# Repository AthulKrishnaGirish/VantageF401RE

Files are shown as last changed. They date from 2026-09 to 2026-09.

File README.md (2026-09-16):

# VantageF401RE

### STM32F401RE Evaluation & Development Board

**Mixed Traces PCB Design Competition — 2026  —**
**Submission by, Athul Krishna Girish**

---

## Project Overview

**VantageF401RE** is an independently designed, compact **2-layer STM32F401RE-based evaluation and development board** developed in KiCad as part of the **Mixed Traces PCB Design Competition 2026**.

The board is built around the **STM32F401RET6** microcontroller and integrates the essential features expected from a development board, including regulated power, USB connectivity, SWD programming/debugging, UART, SPI, I²C, GPIO expansion, reset and boot control, user indicators, and supporting protection and decoupling circuitry.

The design was developed independently with the **STM32 NUCLEO-F401RE** used as a functional and architectural reference. The VantageF401RE schematic, component arrangement, PCB placement, and routing were independently developed and are not a direct copy of the NUCLEO PCB layout.

---

## Project Status

### Completed — Final Design

The VantageF401RE schematic and PCB layout have been completed in KiCad.

The project includes:

- Complete STM32F401RET6-based schematic
- Power supply and 3.3 V regulation
- USB-C power and USB 2.0 interface
- USB ESD protection
- SWD programming/debugging interface
- UART interface
- SPI interface
- I²C interface
- GPIO expansion
- Reset and BOOT selection circuitry
- User button and LED
- Power and USB status indicators
- External 5 V input
- Crystal oscillator
- MCU power decoupling
- Test points
- Two-layer PCB layout
- Ground copper zones
- ERC and DRC verification
- Final Gerber and drill file generation
- Final component list and design documentation

The final PCB design achieved **0 reported DRC errors**, and the final manufacturing files were generated from the completed PCB layout.

> **Note:** The project was developed and verified as a PCB design in KiCad. No physical fabrication or hardware testing is claimed as part of this submission.

---

## Key Specifications

| Parameter | Specification |
|---|---|
| **Board Name** | VantageF401RE |
| **MCU** | STM32F401RET6 |
| **MCU Package** | LQFP-64 |
| **PCB Layers** | 2 copper layers |
| **PCB Dimensions** | 80 mm × 60 mm |
| **Design Software** | KiCad |
| **Logic Supply** | 3.3 V |
| **USB Interface** | USB Type-C / USB 2.0 |
| **Programming & Debugging** | SWD |
| **Communication Interfaces** | UART, SPI, I²C |
| **GPIO Expansion** | 20-pin header |
| **External Power** | 5 V input |
| **PCB Verification** | ERC / DRC |
| **Fabrication Requirement** | Not required |

---

## Main Features

### 1. STM32F401RET6 Core

The board uses the **STM32F401RET6**, a 64-pin LQFP STM32F4-series microcontroller.

The MCU section includes:

- 3.3 V digital supply
- Analog supply connection
- VCAP capacitor
- Local decoupling capacitors
- External HSE crystal
- Reset circuitry
- BOOT0 configuration
- SWD programming/debugging access

---

### 2. Power Supply

The board provides a regulated **3.3 V supply** for the STM32F401RET6 and peripheral circuitry.

**Power inputs**

- USB-C 5 V input
- External 5 V input

**Regulation**

An **AP2112K-3.3 LDO regulator** converts the incoming 5 V supply to 3.3 V.

The power section includes:

- Input decoupling
- Output decoupling
- 3.3 V bulk capacitance
- Power indication
- External-input protection

An **SS14 Schottky diode** is included on the external 5 V input path for protection.

---

### 3. USB-C Interface

The board provides a USB Type-C connector for power and USB 2.0 data connectivity.

The USB section includes:

- USB-C receptacle
- USB 2.0 D+ and D− connections
- CC1 and CC2 configuration resistors
- USB ESD protection
- USB D+ and D− series resistors
- USB status indicator

The USB data path uses the STM32F401RE USB pins:

- **PA11 — USB_DM**
- **PA12 — USB_DP**

---

### 4. USB ESD Protection

A **USBLC6-2SC6** protection device is placed close to the USB connector.

The protection network is incorporated into the USB data path to provide ESD protection for the USB D+ and D− lines.

The USB signal path is organized as:

```text
USB-C
  ↓
USB D+ / D−
  ↓
USB ESD Protection
  ↓
22 Ω Series Resistors
  ↓
STM32F401RET6
```

---

### 5. SWD Programming & Debugging

A dedicated 5-pin SWD header is provided for programming and debugging the STM32F401RET6.

The interface provides:

- VCC
- SWDIO
- GND
- SWCLK
- NRST

MCU connections:

- PA13 — SWDIO
- PA14 — SWCLK
- NRST — Reset

Dedicated test points are also provided for SWDIO, SWCLK, and NRST.

---

### 6. UART Interface

A dedicated 4-pin UART header provides easy access to the serial communication interface.

| UART Signal | MCU Pin |
|---|---|
| UART_TX | PA2 |
| UART_RX | PA3 |
| VCC | +3V3 |
| GND | GND |

---

### 7. SPI Interface

A dedicated 6-pin SPI header is provided.

| SPI Signal | MCU Pin |
|---|---|
| SPI_SCK | PA5 |
| SPI_MISO | PA6 |
| SPI_MOSI | PA7 |
| SPI_CS | PA4 |
| VCC | +3V3 |
| GND | GND |

---

### 8. I²C Interface

A dedicated 4-pin I²C header is provided with external pull-up resistors.

| I²C Signal | MCU Pin |
|---|---|
| I2C_SCL | PB6 |
| I2C_SDA | PB7 |
| VCC | +3V3 |
| GND | GND |

Two 4.7 kΩ pull-up resistors are provided for the I²C lines.

---

### 9. GPIO Expansion

A dedicated 20-pin GPIO expansion header provides access to multiple STM32 GPIOs along with power and ground.

The expansion header provides access to signals including:

- PA0
- PA1
- PA8
- PA9
- PA10
- PB2
- PB10
- PC6
- PB12–PB15
- PC0–PC5
- +3V3
- GND

This provides flexibility for connecting external sensors, modules, displays, and other peripherals.

---

### 10. Reset & Boot Control

**Reset**

The NRST line includes:

- 10 kΩ pull-up resistor
- Dedicated reset pushbutton
- SWD NRST connection
- NRST test point

**Boot Selection**

BOOT0 includes:

- 10 kΩ pull-down resistor
- Dedicated BOOT selection header
- +3V3 selection capability

This allows the boot configuration of the STM32F401RET6 to be conveniently controlled.

---

## User Interface

The board includes dedicated user indicators and controls.

**User LED**

- D1 — USER_LED
- Controlled through PB0
- R3 = 330 Ω current-limiting resistor

**User Button**

- SW2 — USER_BTN
- Connected to PB1
- R4 = 10 kΩ pull-up resistor

**Power LED**

- D2 — POWER
- R9 = 1 kΩ current-limiting resistor

**USB Status LED**

- D4 — USB_STATUS
- Controlled through PB5
- R12 = 1 kΩ current-limiting resistor

---

## Clock Circuit

The MCU uses an external 8 MHz HSE crystal.

The clock section consists of:

- Y1 — 8 MHz crystal
- C2 — 18 pF
- C3 — 18 pF

The crystal and its load capacitors are placed close to the MCU to maintain a compact and controlled clock path.

---

## Decoupling & Power Integrity

Local decoupling is provided around the STM32F401RET6 and the power-supply circuitry.

The design includes:

- VDD decoupling capacitors
- VCAP capacitor
- Analog supply decoupling
- 3.3 V bulk capacitance
- LDO input and output capacitors

The final PCB placement keeps critical decoupling components close to their respective power pins and maintains short power/ground paths.

---

## PCB Design

The VantageF401RE PCB was designed as a two-layer board while maintaining the competition's maximum board-size requirement.

**Final board dimensions:** 80 mm × 60 mm

**PCB design considerations**

- Central MCU placement
- Short critical signal paths
- Dedicated power section
- USB connector at the board edge
- Accessible programming/debugging header
- Clearly grouped communication headers
- GPIO expansion access
- Local MCU decoupling
- Ground copper zones
- Organized component placement
- Practical connector accessibility
- Compact routing while maintaining design-rule compliance

The PCB layout was independently developed rather than directly reproducing the NUCLEO-F401RE PCB layout.

---

## Final Component Set

The completed design contains 47 populated component references:

| Category | Quantity |
|---|---|
| MCU | 1 |
| USB Protection | 1 |
| Voltage Regulator | 1 |
| Connectors | 8 |
| Crystal | 1 |
| Resistors | 12 |
| Capacitors | 12 |
| LEDs | 3 |
| Diode | 1 |
| Switches | 2 |
| Test Points | 5 |
| **Total** | **47** |

The complete component list is available in:
`bom/VantageF401RE_Final_Component_List.xlsx`

The component reference designators in the final documentation follow the final schematic.

---

## Verification

The design was checked using KiCad's electrical and physical design-rule verification tools.

**ERC — Electrical Rules Check**

- 0 violations
- 0 errors
- 0 warnings

**DRC — Design Rules Check**

- 0 reported DRC errors

The final Gerber and drill files were generated from the completed PCB layout after routing and design-rule verification.

---

## Repository Contents

The repository contains the complete design and supporting documentation.

```text
VantageF401RE/
│
├── bom/
│   └── VantageF401RE_Final_Component_List.xlsx
│
├── docs/
│   ├── Major Decisions.md
│   └── Initial Block Diagram.png
│
├── gerbers/
│   ├── VantageF401RE_Gerbers.zip
│   └── README.md
│
├── kicad/
│   ├── VantageF401RE.kicad_sch
│   ├── VantageF401RE.kicad_pcb
│   ├── VantageF401RE.kicad_pro
│   └── README.md
│
├── pdf/
│   ├── VantageF401RE_Final_Design_Report.pdf
│   └── README.md
│
├── results/
│   ├── ERC / DRC and validation results
│   └── README.md
│
└── README.md
```

---

### Folder Description

| [`bom/`](bom/) |
Contains the final component list and BOM-related documentation.
`VantageF401RE_Final_Component_List.xlsx` — provides the final component references, values, footprints, functions, and interface mapping.

| [`docs/`](docs/) |
Contains supporting project documentation, design information, and technical documentation associated with the development of the board.

| [`gerbers/`](gerbers/) |
Contains the final manufacturing output package.
`VantageF401RE_Gerbers.zip` — includes the final copper, solder-mask, silkscreen, paste, board-outline, and drill outputs generated from KiCad.

| [`kicad/`](kicad/) |
Contains the primary editable KiCad design files, including:

- Schematic
- PCB layout
- Supporting KiCad project files

These files represent the actual circuit and PCB implementation of VantageF401RE.

| [`pdf/`](pdf/) |
Contains the final technical design report prepared for the competition submission.
`VantageF401RE_Final_Design_Report.pdf` — provides a consolidated description of the board architecture, design decisions, implementation, verification, and final outcome.

| [`results/`](results/) |
Contains design verification and validation outputs, including ERC/DRC-related results and other relevant design-check documentation.

---

## Competition Compliance

| Requirement | VantageF401RE |
|---|---|
| STM32F401RE MCU | ✓ |
| Maximum 100 mm × 100 mm | ✓ |
| Exactly 2 copper layers | ✓ |
| Power input | ✓ |
| Voltage regulation | ✓ |
| Decoupling | ✓ |
| Power indication | ✓ |
| SWD interface | ✓ |
| Reset button | ✓ |
| User button | ✓ |
| User LED | ✓ |
| UART | ✓ |
| SPI | ✓ |
| I²C | ✓ |
| GPIO expansion | ✓ |
| USB interface | ✓ |
| ERC verification | ✓ |
| DRC verification | ✓ |
| Gerber generation | ✓ |
| Final BOM | ✓ |
| Technical documentation | ✓ |

---

## Design Philosophy

The VantageF401RE was designed with the following priorities:

- Electrical correctness
- Reliable power distribution
- Practical peripheral access
- Compact PCB organization
- Clear interface grouping
- Debugging accessibility
- Protection and robustness
- Expandability
- Manufacturing-oriented PCB design
- Clean and structured documentation

The design balances the requirements of a development board with the constraints of a compact two-layer PCB.

---

## Final Outcome

The VantageF401RE project progressed from initial architecture and component planning to a completed schematic, PCB layout, verification, and manufacturing-output generation.

The final repository provides the editable KiCad design files together with the final component list, verification results, Gerber package, and technical design report.

The result is a compact, independently developed STM32F401RE evaluation and development board intended to provide convenient access to programming, debugging, communication, GPIO expansion, USB connectivity, and basic user-interface functionality.

---

## Project Information

- **Project:** VantageF401RE
- **Board:** STM32F401RE Evaluation & Development Board
- **Competition:** Mixed Traces PCB Design Competition — 2026
- **Organizer:** Mixed Signals — Electronics Association of MEC
- **Design Tool:** KiCad
- **MCU:** STM32F401RET6
- **PCB:** 2-layer, 80 mm × 60 mm

---

## Acknowledgement

Developed as a submission for the Mixed Traces PCB Design Competition 2026, organized by Mixed Signals — Electronics Association of MEC.

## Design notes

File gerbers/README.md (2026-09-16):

# VantageF401RE — Gerber Fabrication Files

This folder contains the **final Gerber and drill files** generated from the completed VantageF401RE PCB design for submission to the **Mixed Traces PCB Design Competition** by Mixed Signals, Electronics Association of MEC.

## Gerber Package

**File:** `VantageF401RE_Gerbers.zip`

The ZIP archive contains the manufacturing files required to reproduce the designed 2-layer PCB.

## Included Fabrication Files

The Gerber package contains:

- Front Copper — F.Cu
- Back Copper — B.Cu
- Front Solder Mask — F.Mask
- Back Solder Mask — B.Mask
- Front Silkscreen — F.Silkscreen
- Back Silkscreen — B.Silkscreen
- Front Paste — F.Paste
- Back Paste — B.Paste
- Board Outline — Edge.Cuts
- Excellon Drill File(s)
- Gerber Job File, where applicable

## PCB Specifications

- **Board:** VantageF401RE
- **PCB Type:** 2-layer
- **Board Dimensions:** 80 mm × 60 mm
- **Design Software:** KiCad
- **MCU:** STM32F401RET6

## Verification

The final PCB layout was checked using KiCad's Design Rules Checker (DRC) and completed with **0 reported DRC errors**.

The Gerber files were generated from the final PCB layout after completion of component placement, routing, copper zones, and design-rule verification.

## Fabrication Note

The Gerber ZIP contains the manufacturing outputs of the VantageF401RE PCB design. These files are provided for competition submission and fabrication reference.

The PCB has **not been physically fabricated or hardware-tested** as part of this design submission.

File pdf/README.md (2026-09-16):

# VantageF401RE — Final Design Report

This folder contains the **final drafted design report** prepared for the **Mixed Traces PCB Design Competition** by Mixed Signals, Electronics Association of MEC.

## Final Report

**File:** `VantageF401RE_Final_Design_Report.pdf`

The report documents the completed design and development of the **VantageF401RE**, a custom 2-layer STM32F401RE-based evaluation and development board designed in KiCad.

## Contents of the Report

The final report includes:

- Project overview and objectives
- Problem statement and proposed solution
- System architecture and functional block diagram
- STM32F401RET6 microcontroller selection
- Power supply and 3.3 V regulation
- USB-C power and USB 2.0 interface
- USB ESD protection
- SWD programming and debugging interface
- UART, SPI, and I²C interfaces
- GPIO expansion
- Reset and BOOT selection circuitry
- User button and LED indicators
- External 5 V input and protection
- Crystal oscillator and clock circuitry
- MCU decoupling and power integrity considerations
- PCB component placement and routing
- 2-layer PCB design
- Design considerations and major design decisions
- ERC and DRC verification
- Final board specifications
- Bill of Materials overview
- Final design outcome and conclusion

## Final Board Specifications

- **MCU:** STM32F401RET6
- **PCB Layers:** 2 copper layers
- **PCB Size:** 80 mm × 60 mm
- **Design Tool:** KiCad
- **USB Interface:** USB Type-C, USB 2.0
- **Debug Interface:** SWD
- **Communication Interfaces:** UART, SPI, I²C
- **Expansion:** 20-pin GPIO header
- **Power:** USB-C 5 V input / external 5 V input
- **Logic Supply:** 3.3 V
- **Verification:** ERC completed with 0 violations; DRC completed with 0 reported errors

## Note

This report represents the **final PCB design and documentation** prepared for competition submission. The design was completed and verified in KiCad. No physical fabrication or hardware testing is claimed unless explicitly stated in the report.

For the authoritative circuit implementation and component reference designators, refer to the final KiCad schematic and PCB files in the repository.

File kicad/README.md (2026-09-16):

# VantageF401RE — KiCad Design Files

This folder contains the complete editable **KiCad project files** for the **VantageF401RE**, a custom STM32F401RE-based evaluation and development board designed for the **Mixed Traces PCB Design Competition** by Mixed Signals, Electronics Association of MEC.

The design was developed entirely in **KiCad** as a **2-layer PCB**, with a focus on functionality, accessibility, protection, compact organization, and practical embedded-system development.

---

## Project Files

| File | Description |
|---|---|
| `VantageF401RE.kicad_pro` | Main KiCad project file |
| `VantageF401RE.kicad_sch` | Complete electrical schematic |
| `VantageF401RE.kicad_pcb` | Final 2-layer PCB layout |

These files can be opened and edited using KiCad.

---

## Board Specifications

| Parameter | Specification |
|---|---|
| MCU | STM32F401RET6 |
| MCU Package | LQFP-64 |
| PCB Layers | 2 |
| Board Size | 80 mm × 60 mm |
| Design Tool | KiCad |
| USB Interface | USB Type-C, USB 2.0 |
| Supply Voltage | 3.3 V regulated |
| External Input | 5 V |
| Debug Interface | SWD |
| Oscillator | 8 MHz external crystal |

The board size remains well within the competition's maximum permitted **100 mm × 100 mm** area.

---

## Main Functional Blocks

The VantageF401RE integrates the following functional sections:

### 1. STM32F401RET6 Core

The STM32F401RET6 serves as the main processing device.

The design includes:

- External 8 MHz crystal oscillator
- VCAP1 capacitor
- MCU power decoupling
- Analog supply decoupling
- Reset circuitry
- BOOT0 configuration
- Dedicated programming/debug access

---

### 2. Power Management

The power section provides a regulated 3.3 V supply for the MCU and peripherals.

Features include:

- USB-C 5 V input
- External 5 V input
- AP2112K-3.3 LDO regulator
- Input and output capacitors
- Schottky-diode protection for external 5 V input
- Power LED
- 3.3 V and GND test points

---

### 3. USB Interface

A USB-C connector is provided for USB 2.0 connectivity and 5 V power input.

The USB section includes:

- USB Type-C receptacle
- USB D+ and D− connections
- CC1 and CC2 resistors
- USB ESD protection using USBLC6-2SC6
- USB data-line series resistors
- USB status LED
- Dedicated USB 5 V power rail

The USB data path is protected before reaching the STM32 USB pins.

---

### 4. SWD Programming and Debugging

A dedicated 5-pin SWD header is provided for programming and debugging the STM32.

The interface exposes:

- VCC
- SWDIO
- GND
- SWCLK
- NRST

Test points are also provided for SWDIO, SWCLK, and NRST.

---

### 5. Reset and Boot Configuration

The board provides dedicated controls for reliable startup and debugging.

Features include:

- Hardware reset push button
- NRST pull-up resistor
- BOOT0 pull-down resistor
- BOOT selection header

---

### 6. Communication Interfaces

Dedicated headers are provided for commonly used embedded communication protocols.

#### UART

- UART TX
- UART RX
- 3.3 V
- GND

#### SPI

- SPI SCK
- SPI MISO
- SPI MOSI
- SPI CS
- 3.3 V
- GND

#### I²C

- I²C SCL
- I²C SDA
- 3.3 V
- GND
- Dedicated pull-up resistors

---

### 7. GPIO Expansion

A dedicated **2×10 GPIO header** provides convenient access to multiple STM32 GPIO pins along with power and ground connections.

This allows external sensors, displays, modules, and other peripherals to be connected directly to the board.

---

### 8. User Interface

The board includes:

- User push button
- User LED
- Reset button
- Power LED
- USB status LED
- BOOT selection header

These provide basic interaction and visual feedback during development and debugging.

---

### 9. Clock and Decoupling

The MCU clock section uses an external **8 MHz crystal oscillator** with dedicated load capacitors.

The power network includes:

- Local 100 nF MCU decoupling capacitors
- Bulk 4.7 µF decoupling
- Analog supply filtering
- VCAP1 capacitor
- Regulator input/output capacitors

The decoupling components were placed close to their respective power pins and functional blocks during PCB layout.

---

### 10. Test and Debug Access

Dedicated test points are provided for important signals:

- 3.3 V
- GND
- SWDIO
- SWCLK
- NRST

These improve accessibility for oscilloscope probing, debugging, and laboratory measurements.

---

## PCB Layout

The final PCB uses a **2-layer copper stack-up** with an **80 mm × 60 mm** board outline.

The placement was organized into functional regions, including:

- Central STM32 MCU section
- USB and power section near the board edge
- SWD/debug section
- Communication interface headers
- GPIO expansion
- Clock circuitry
- User-control section
- Power indication
- Test points

Ground planes are used to provide continuous ground-return paths and improve overall PCB organization.

The layout was routed while considering component accessibility, signal paths, power distribution, and the physical constraints of a 2-layer board.

---

## Design Verification

The final schematic and PCB were verified using KiCad's electrical and PCB design-rule checking tools.

### ERC

**Electrical Rules Check:**

- Violations: **0**
- Errors: **0**
- Warnings: **0**

### DRC

**Design Rules Check:**

- Reported violations: **0**
- Errors: **0**
- Intentional exclusions: **4**

The intentional exclusions correspond to reviewed USB-C connector mechanical hole-clearance checks associated with the selected footprint.

Detailed ERC and DRC reports are available in the repository's [`results/`](../results/) directory.

---

## Design Approach

The VantageF401RE was designed as a complete development platform rather than only an STM32 breakout board.

The design combines:

**Processing + Power + USB + Debugging + Communication + Expansion + User Interface + Protection**

within a compact 2-layer PCB.

Particular attention was given to:

- Power integrity
- Local decoupling
- USB protection
- Signal accessibility
- Debug accessibility
- Peripheral expansion
- Component placement
- Ground connectivity
- PCB manufacturability
- Design-rule compliance

---

## Related Repository Folders

The complete project is organized into dedicated sections:

### [`bom/`](../bom/)

Contains the component selection and BOM documentation.

### [`docs/`](../docs/)

Contains project documentation, including:

- Major design decisions
- Initial block diagram
- Progress evaluation documentation

### [`results/`](../results/)

Contains the final ERC and DRC verification reports.

### [`gerbers/`](../gerbers/)

Contains the final Gerber and drill files prepared for PCB fabrication.

### [`pdf/`](../pdf/)

Reserved for the final project documentation PDF.

---

## Opening the Project

To inspect or continue development:

1. Install a compatible version of KiCad.
2. Open `VantageF401RE.kicad_pro`.
3. Open the schematic through the KiCad project manager.
4. Open the PCB layout from the same project.

The `.kicad_sch` and `.kicad_pcb` files can also be opened individually when required.

---

## Final Design Status

The VantageF401RE design has completed:

- Component selection
- Schematic development
- PCB component placement
- PCB routing
- Power-system implementation
- USB interface implementation
- SWD interface implementation
- UART, SPI and I²C interfaces
- GPIO expansion
- User interface circuitry
- PCB design-rule verification
- Schematic electrical-rule verification
- Gerber and drill-file generation

The files in this directory represent the **final editable KiCad design** submitted as part of the project.

---

**Project:** VantageF401RE  
**MCU:** STM32F401RET6  
**PCB:** 2-Layer, 80 mm × 60 mm  
**EDA Tool:** KiCad  
**Status:** Final Design Completed

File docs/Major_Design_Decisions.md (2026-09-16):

# Major Design Decisions

The following decisions guided the development of the **VantageF401RE** STM32F401RE-based evaluation and development board.

## 1. MCU Selection

**STM32F401RET6** in the **LQFP-64** package was selected as the main microcontroller.

The device provides sufficient processing capability, memory, GPIO availability, and peripheral interfaces for the intended evaluation and development applications.

## 2. Board Purpose

The VantageF401RE was designed as a **general-purpose STM32 evaluation and development platform**, rather than a minimal MCU breakout board.

The design therefore integrates power management, USB connectivity, debugging, communication interfaces, GPIO expansion, user controls, indicators, and test access on a single board.

## 3. PCB Layer Constraint

The PCB uses **exactly two copper layers**, in accordance with the competition requirements.

The placement and routing strategy was developed with the limitations of a 2-layer design in mind, while maintaining practical signal and ground connectivity.

## 4. Board Size

The final PCB dimensions were selected as **80 mm × 60 mm**, remaining comfortably within the competition's maximum permitted **100 mm × 100 mm** board area.

The dimensions were chosen to provide sufficient space for the required interfaces and supporting circuitry while maintaining a compact development-board form factor.

## 5. Programming and Debugging

A dedicated **5-pin SWD interface** was implemented for programming and debugging the STM32.

The SWD interface provides:

- VCC
- SWDIO
- GND
- SWCLK
- NRST

An onboard ST-Link programmer/debugger was intentionally not included, allowing the board to remain simpler and more compact while supporting external SWD programmers/debuggers.

## 6. USB Interface

A **USB Type-C interface** was implemented to provide USB 2.0 connectivity and 5 V power input.

The USB section includes:

- USB D+ and D− connections
- CC1 and CC2 resistors
- Dedicated USB ESD protection
- USB data-line series resistors
- USB 5 V power rail
- USB status indication

The USB interface was designed as both a functional communication interface and a convenient primary power source for the board.

## 7. Power Architecture

A dedicated **AP2112K-3.3 LDO regulator** was selected to generate the regulated 3.3 V supply required by the STM32 and associated circuitry.

The power architecture supports:

- USB-C 5 V input
- External 5 V input
- Schottky-diode protection on the external 5 V path
- 3.3 V regulation
- Regulator input and output decoupling
- MCU power decoupling
- Analog supply decoupling
- Power indication

This provides a practical and protected power system while keeping the circuitry compact.

## 8. Communication Interfaces

Dedicated headers were provided for commonly used embedded communication protocols:

- **UART**
- **SPI**
- **I²C**

These interfaces were exposed with appropriate power and ground connections to simplify connection to external modules and peripherals.

## 9. GPIO Expansion

A dedicated **2×10 GPIO header** was included to expose multiple STM32 GPIOs along with power and ground connections.

The expansion interface was designed to support external sensors, displays, modules, and other experimental circuits without requiring modification to the main PCB.

## 10. Reset and Boot Configuration

Dedicated hardware controls were implemented for reliable startup and development.

The design includes:

- Hardware reset push button
- NRST pull-up resistor
- BOOT0 pull-down resistor
- BOOT selection header

This provides convenient control over reset and boot-mode selection during development and debugging.

## 11. User Interface and Indicators

The board includes dedicated visual and user-control elements:

- User push button
- User LED
- Reset button
- Power LED
- USB status LED

These features provide immediate feedback and improve usability during firmware development and hardware testing.

## 12. Clock and Decoupling Strategy

An external **8 MHz crystal oscillator** was selected for the MCU clock source.

The crystal and its load capacitors were placed close to the corresponding MCU pins.

The design also incorporates local power decoupling, including:

- 100 nF MCU decoupling capacitors
- 4.7 µF bulk decoupling
- Analog supply decoupling
- VCAP1 capacitor
- Regulator input/output capacitors

The placement strategy prioritizes short connections between supply pins and their associated decoupling components.

## 13. Protection and Reliability

Protection features were included where they provide practical benefit without unnecessarily increasing board complexity.

The USB interface uses dedicated **ESD protection**, while the external 5 V input incorporates a Schottky-diode protection path.

Power filtering and local decoupling were also incorporated to improve supply stability and reduce the impact of transient disturbances.

## 14. Test and Debug Accessibility

Dedicated test points were included for important signals:

- 3.3 V
- GND
- SWDIO
- SWCLK
- NRST

These provide convenient access for debugging, probing, waveform measurement, and laboratory testing.

## 15. PCB Organization and Placement

The PCB was organized into functional regions to improve accessibility and simplify routing.

Major sections include:

- STM32 MCU core
- USB interface
- Power regulation
- SWD/debug interface
- Communication interfaces
- GPIO expansion
- Clock circuitry
- User controls and indicators
- Test points

Components were positioned with consideration for signal paths, accessibility, power distribution, and the constraints of a two-layer PCB.

## 16. Ground and Power Integrity

Power integrity was treated as an important part of the PCB design.

The design uses:

- Local decoupling
- Dedicated bulk capacitors
- Analog supply filtering
- Organized power distribution
- Ground planes
- Short connections around critical power components

The routing strategy was developed to provide practical return-current paths while maintaining clean functional organization.

## 17. Originality

The **NUCLEO-F401RE** was used as a functional and architectural reference for understanding the STM32F401RE platform and its development-board requirements.

However, the VantageF401RE schematic organization, component selection, functional additions, component placement, board dimensions, and PCB routing were independently developed.

The final PCB is therefore a custom implementation rather than a direct reproduction of the NUCLEO-F401RE layout.

## 18. Feature Selection and Optimization

Additional features were selected based on their practical usefulness, available board area, routing complexity, component count, and overall design value.

Rather than adding features solely for complexity, the design prioritizes features that improve the board's usefulness as an evaluation and development platform.

## 19. Verification

The completed design was validated using KiCad's electrical and PCB design-rule checking tools.

The final results were:

- **ERC: 0 violations**
- **DRC: 0 reported violations**
- **4 intentional DRC exclusions**, corresponding to reviewed USB-C connector mechanical clearance checks

The detailed verification reports are available in the `results/` directory.

## 20. Final Design Objective

The final VantageF401RE design combines:

**Functionality + Expandability + Protection + Debug Accessibility + Power Management + Compact 2-Layer Design + Verification**

The overall objective was to create a practical and professionally organized STM32 development platform that satisfies the competition requirements while providing useful features for real-world embedded-system experimentation.

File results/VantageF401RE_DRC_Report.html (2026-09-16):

** Drc report for VantageF401RE.kicad_pcb ** ** Created on 2026-09-17T00:43:25 ** ** Report includes: Errors, Warnings ** ** Found 0 DRC violations ** ** Found 0 unconnected pads ** ** Found 0 Footprint errors ** ** Ignored checks ** - Footprint has no courtyard defined - Track endpoint not centered on via - Tuning profile track geometries - Footprint doesn't match symbol's footprint filters - Footprint component type doesn't match footprint pads ** End of Report **

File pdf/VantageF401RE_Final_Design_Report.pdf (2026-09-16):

MIXED TRACES PCB DESIGN COMPETITION

Organized by Mixed Signals, Electronics Association of MEC

# VantageF401RE

## STM32F401RE Evaluation & Development Board

Final Design and Evaluation Report

Custom Two-Layer STM32F401RET6 Development Platform
Designed in KiCad EDA | Compact 80 mm × 60 mm Form Factor

Status: Completed Design — Gerber / Drill Files Generated for Submission No physical fabrication was performed; fabrication was not required by the competition.

VantageF401RE — Final Design and Evaluation Report | Mixed Traces PCB Design Competition

## Table of Contents

## 1. Executive Summary

VantageF401RE is a custom two-layer development and evaluation board designed around the STM32F401RET6 microcontroller for submission to the Mixed Traces PCB Design Competition, organized by Mixed Signals, the Electronics Association of MEC. The competition specified a fixed microcontroller, a maximum board size of 100 mm × 100 mm, a strict two-copper-layer constraint, and a defined set of mandatory interfaces, while permitting the NUCLEO-F401RE to be consulted as a functional reference rather than a layout template.

Rather than implementing a minimal microcontroller breakout, the design was elected to treat the competition brief as an opportunity to build a compact, general-purpose STM32 development platform that would remain useful beyond the scope of the competition itself. The resulting board integrates a regulated 3.3 V power architecture, a USB-C interface providing both power delivery and USB 2.0 connectivity with dedicated ESD protection, a Serial Wire Debug (SWD) header for external programmer/debugger use, reset and BOOT0 selection circuitry, independently broken-out UART, SPI and I²C interfaces, a 2×10 GPIO expansion header, user and status indicators, an external 8 MHz crystal oscillator, structured decoupling across the digital and analog supply domains, and dedicated test points for laboratory probing.

The complete design was captured and verified in KiCad. All required interfaces were routed within a final board outline of 80 mm × 60 mm, well inside the 100 mm × 100 mm competition limit, using exactly two copper layers. The finished schematic and PCB layout were checked using KiCad's Electrical Rules Check (ERC) and Design Rules Check (DRC) tooling. The completed ERC returned zero violations, and the completed DRC returned zero reported violations, with four intentional exclusions associated with reviewed USB-C connector mechanical hole-clearance checks tied to the selected connector footprint.

Gerber and NC drill files were generated from the finished layout for competition submission. In accordance with the competition rules, no physical fabrication, assembly, or hardware bring-up was performed or is claimed as part of this report; the deliverable is a design-level submission supported by design-level verification. This report documents the problem statement, architecture, circuit-level design decisions, PCB placement and routing strategy, the challenges encountered and how they were addressed, the verification results obtained, and the notable engineering characteristics that distinguish VantageF401RE as a feature-rich, independently developed STM32 evaluation platform.

## 2. Introduction

### 2.1 Project Background

STM32-based evaluation boards such as the ST NUCLEO series are widely used as reference platforms for learning embedded systems development, prototyping firmware, and validating peripheral interfacing before committing to a production design. The Mixed Traces PCB Design Competition asked participating teams to design an original two-layer evaluation board around the STM32F401RE microcontroller, using the NUCLEO-F401RE strictly as a functional reference for understanding how the device is typically supported, while prohibiting direct reproduction of its PCB layout.

This constraint framed the project as both a circuit-design exercise and a layout-engineering exercise: the team needed to reproduce the functional guarantees that make an STM32F401RE board usable for development (clean power, reliable programming access, accessible peripherals) while independently deriving the schematic organization, placement, and routing within a much smaller, self-imposed footprint.

### 2.2 Problem Statement

The core design problem was to deliver a fully functional, independently laid-out STM32F401RE development board that satisfies a fixed set of mandatory interfaces and protections, fits within a 100 mm × 100 mm competition envelope, and can be routed cleanly using only two copper layers — a layer count that removes the routing flexibility a dedicated internal ground or power plane would otherwise provide.

### 2.3 Objectives

- Design a complete, reusable STM32F401RET6 development and evaluation platform rather than a minimal MCU breakout.
- Satisfy every mandatory competition interface: MCU, power input, voltage regulation, decoupling, power indication, SWD, reset, user button, user LED, power LED, UART, SPI, I²C, GPIO expansion, and USB.
- Add protective and practical features — USB ESD protection, an external 5 V input path, USB status indication, BOOT0 selection, test points, and dedicated expansion headers — that improve robustness and usability.
- Independently develop the schematic organization, component placement, board dimensions, and routing, using the NUCLEO-F401RE strictly as a functional reference.
- Complete the design to a verifiable state in KiCad and generate fabrication-ready outputs for submission.

### 2.4 Competition Constraints

The following constraints, summarized in Table 1, governed every design decision made for VantageF401RE.

Table 1. Summary of competition requirements and constraints.

Constraint | Requirement
Microcontroller | Fixed: STM32F401RE / STM32F401RET6
Board type | Original two-layer STM32F401RE evaluation/development board
Maximum board size | 100 mm × 100 mm
Copper layers | Exactly two
Reference design | NUCLEO-F401RE permitted as a functional reference only
Layout originality | Direct copying of the NUCLEO-F401RE PCB layout prohibited
Fabrication | Not required for the competition
Mandatory interfaces | MCU, power input, regulation, decoupling, power LED, SWD, reset button, user button, user LED, UART, SPI, I²C, GPIO expansion, USB

## 3. Proposed Solution

### 3.1 Overall Architecture

VantageF401RE is organized around the STM32F401RET6 as the central processing element, with all supporting circuitry grouped into functional subsystems: power input and regulation, USB-C connectivity with ESD protection, programming and debug access, user interaction and indication, clock generation, and peripheral breakout (UART, SPI, I²C, and general-purpose GPIO expansion). Each subsystem was designed, decoupled, and placed as a discrete functional block, which simplified both schematic capture and PCB floor-planning under the two-layer constraint.

Two independent power sources — USB-C 5 V and an externally supplied 5 V input — are combined ahead of a single AP2112K-3.3 linear regulator that produces the board's 3.3 V core rail. This keeps the downstream power distribution, decoupling, and power indication circuitry unified regardless of which supply is in use.

### 3.2 Functional Block Diagram

USB-C Connector (Power + USB 2.0)
↓

USB ESD Protection (USBLC6-2SC6)
↓

STM32F401RET6 (LQFP-64)
↓

UART · SPI · I²C · GPIO Expansion

Figure 1. Overall VantageF401RE functional block diagram — primary data and control path.

In parallel with the primary signal path shown in Figure 1, the power subsystem feeds the MCU directly, while SWD, reset, BOOT0, the clock circuit, user controls, indicators, and test points connect to the STM32F401RET6 as supporting subsystems, as summarized in Figure 2.

Supporting Subsystem | Connection to STM32F401RET6
Power (USB-C 5 V / External 5 V via SS14 → AP2112K-3.3 → +3V3) | VDD / VDDA pins (19, 32, 48, 64, 13); VSS/VSSA (18, 31, 47, 63, 12); VBAT (1)
SWD Debug Header (J1) | PA13 (SWDIO), PA14 (SWCLK), NRST
Reset Circuit (R1, SW1) | NRST (pin 7)
BOOT Selection (R2, J8) | BOOT0 (pin 60)
8 MHz Crystal (Y1, C2, C3) | PH0-OSC_IN (pin 5), PH1-OSC_OUT (pin 6)
User LED / Button (D1, SW2) | PB0 (pin 26), PB1 (pin 27)
Test Points (TP1–TP5) | +3V3, GND, SWDIO, SWCLK, NRST

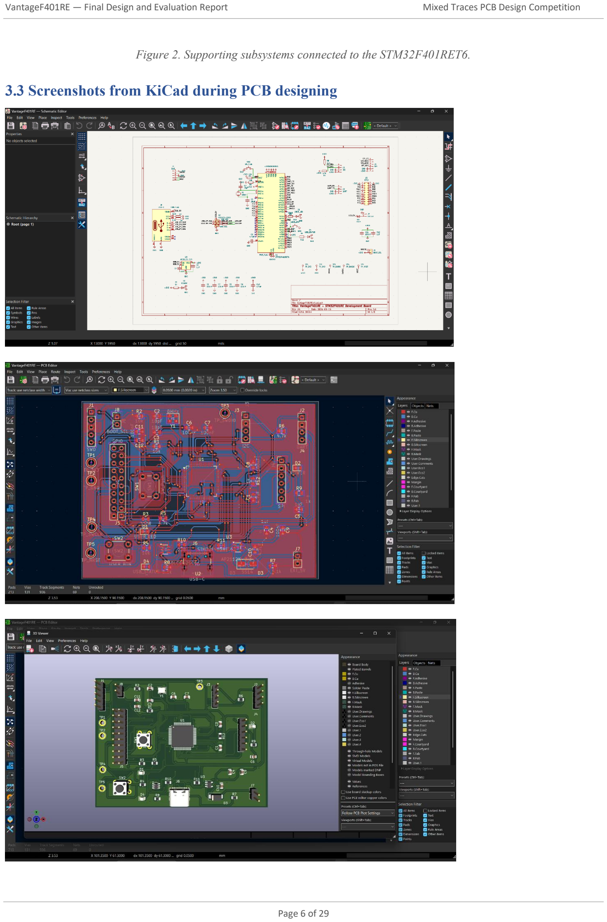
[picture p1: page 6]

Figure 2. Supporting subsystems connected to the STM32F401RET6.

### 3.3 Screenshots from KiCad during PCB designing

## 4. Circuit Architecture

### 4.1 STM32 Processing Core

The | design | uses | the | STM32F401RET6 | in | the | LQFP-64 | package | (symbol
MCU_ST_STM32F4:STM32F401RETx, footprint Package_QFP:LQFP-64_10x10mm_P0.5mm) as the sole processing element. The MCU is placed approximately at the geometric center of the PCB, acting as the primary routing hub around which every functional block is organized.

Power pins are grouped and connected as follows: VDD pins 19, 32, 48 and 64 to +3V3; VSS pins 18, 31, 47 and 63 to GND; the combined VDDA/VREF+ pin 13 to +3V3; the combined VSSA/VREF− pin 12 to GND; and VBAT (pin 1) to +3V3. VCAP1 (pin 30) is decoupled to GND with a dedicated 4.7 µF capacitor (C1), as required for the internal regulator of the STM32F4 series.

Design Note — Pin Availability
The STM32F401RET6 does not expose PB11 as a usable GPIO in this package/variant; the corresponding physical location is occupied by VCAP1. The GPIO expansion header mapping in this report and in the schematic reflects this correctly and does not present PB11 as an available signal.

### 4.2 Power System

The board implements a single regulated 3.3 V rail derived from a 5 V input bus (USB_5V) that can be sourced from either the USB-C connector or an external 5 V input. Regulation is performed by U3, an AP2112K-3.3 low-dropout linear regulator in a SOT-23-5 package, wired with VIN (pin 1) and EN (pin 3) to USB_5V, VOUT (pin 5) to +3V3, and GND (pin 2) to GND. Input and output decoupling is provided by C4 (1 µF, USB_5V to GND) and C5 (1 µF, +3V3 to GND) respectively, placed close to the regulator body.

The external 5 V input is presented on header J7, where pin 1 passes through D3, an SS14 Schottky diode, before joining the USB_5V net, and pin 2 connects to GND. The SS14 diode provides reverse-current and basic input protection on the externally supplied rail, isolating it from the USB-C supply path while allowing either source to power the board without conflict.

Power presence is indicated by a dedicated LED stage: +3V3 feeds R9 (1 kΩ) in series with D2 (the POWER LED) to GND. Two power test points are also provided — TP1 on +3V3 and TP2 on GND — for convenient meter or oscilloscope probing during laboratory use.

Table 2. Power system component summary.

Reference | Function | Value / Part
U3 | 3.3 V linear regulator | AP2112K-3.3, SOT-23-5
D3 | External-input protection diode | SS14 Schottky
C4 | Regulator input decoupling | 1 µF
C5 | Regulator output decoupling | 1 µF
R9 / D2 | Power indication | 1 kΩ / LED

Reference | Function | Value / Part
TP1 / TP2 | Power test points | +3V3 / GND

### 4.3 USB Interface

USB | connectivity | is | provided | through | J6, | a | USB-C | receptacle | (footprint
Connector_USB:USB_C_Receptacle_GCT_USB4105-xx-A_16P_TopMnt_Horizontal), supplying both the USB_5V power rail and USB 2.0 full-speed data. Configuration-channel pins CC1 and CC2 are each terminated to GND through 5.1 kΩ resistors, which is the standard passive termination that presents the connector as a USB 2.0 sink/peripheral to an attached USB-C source. The SBU1 and SBU2 sideband pins are left not-connected, as they are not required for a USB 2.0-only implementation.

### 4.4 USB ESD Protection

The D+ and D− data lines are routed from the USB-C connector into U2, a USBLC6-2SC6 ESD-protection device in a SOT-23-6 package, before continuing to the MCU. The raw connector-side nets USB_DP_RAW and USB_DM_RAW enter U2 at pins 1 and 3 respectively; U2 pin 2 and pin 5 connect to GND and USB_5V for device biasing and clamping reference; and the protected, MCU-side nets USB_DP_SER and USB_DM_SER leave U2 at pins 6 and 4 respectively. From there, 22 Ω series resistors (R10 on D+, R11 on D−) connect to the final USB_DP and USB_DM nets, which terminate at PA12 and PA11 on the MCU.

Design Note — ESD Device Pinout
U2 pin 1 (USB_DP_RAW) and pin 6 (USB_DP_SER) are distinct nets connected through the internal protection element, not shorted together; the same applies to pin 3 (USB_DM_RAW) and pin 4 (USB_DM_SER). This is deliberate: the ESD device is placed electrically between the exposed connector pins and the MCU-facing pins so that transient events at the connector are clamped before reaching PA11/PA12.

Placing U2 close to the USB-C connector, ahead of the series resistors and the MCU, ensures that ESD events are clamped as close as possible to the point of entry, minimizing the length of unprotected trace exposed to the connector.

### 4.5 SWD Debug Interface

Programming and debugging access is provided through J1, a dedicated 5-pin SWD header, wired as pin 1 = +3V3, pin 2 = SWDIO, pin 3 = GND, pin 4 = SWCLK, and pin 5 = NRST. On the MCU side, SWDIO connects to PA13 (pin 46), SWCLK connects to PA14 (pin 49), and the reset line connects to NRST (pin 7).

VantageF401RE does not include an onboard ST-Link or other integrated debug-probe circuitry. This is a deliberate design choice: omitting the programmer section keeps the board compact and keeps its component budget and layout area focused on the evaluation platform itself, while still providing full programming and debugging capability through any external SWD-compatible probe.

### 4.6 Reset and BOOT

The reset network consists of R1, a 10 kΩ pull-up from NRST (pin 7) to +3V3, and SW1, a momentary push-button connecting NRST to GND. This provides a debounced-by-design, normally-high reset line that can be asserted manually during development.

BOOT mode selection uses R2, a 10 kΩ pull-down on BOOT0 (pin 60), together with J8, a 2-pin BOOT_SEL header where pin 1 connects to BOOT0 and pin 2 connects to +3V3. With J8 open, BOOT0 is held low by R2 and the device boots from the main flash memory in the normal operating mode; bridging J8 pulls BOOT0 high and selects the system bootloader for in-field reprogramming without an external debug probe. Together, the reset and BOOT circuits give the developer convenient, header-level control over reset and boot-mode configuration during firmware development and recovery.

### 4.7 UART

J2 is a dedicated 4-pin UART header, wired as pin 1 = +3V3, pin 2 = GND, pin 3 = UART_TX, and pin 4 = UART_RX. On the MCU side, UART_TX connects to PA2 (pin 16) and UART_RX connects to PA3 (pin 17), providing an independent serial interface for logging, host communication, or bootloader interaction separate from the USB path.

### 4.8 SPI

J4 is a dedicated 6-pin SPI header, wired as pin 1 = +3V3, pin 2 = GND, pin 3 = SPI_SCK, pin 4 = SPI_MISO, pin 5 = SPI_MOSI, and pin 6 = SPI_CS. On the MCU side, SPI_SCK connects to PA5 (pin 21), SPI_MISO to PA6 (pin 22), SPI_MOSI to PA7 (pin 23), and SPI_CS to PA4 (pin 20), giving direct header access to a full SPI master interface for external peripherals such as displays, memory devices, or sensor modules.

### 4.9 I²C

J3 is a dedicated 4-pin I²C header, wired as pin 1 = +3V3, pin 2 = GND, pin 3 = I2C_SCL, and pin 4 = I2C_SDA. On the MCU side, I2C_SCL connects to PB6 (pin 58) and I2C_SDA connects to PB7 (pin 59). Because I²C is an open-drain bus, R6 and R7 (4.7 kΩ each) provide the pull-up resistors required for SCL and SDA to return to a valid logic-high level; without these pull-ups the bus cannot function, since neither the master nor any slave device actively drives a high level on an open-drain line.

### 4.10 GPIO Expansion

J5 is a 2×10 general-purpose expansion header exposing ten GPIO signals alongside power and ground, intended to support sensors, displays, external modules, and general prototyping work beyond the fixed peripheral headers. The complete pin mapping is provided in Table 3 and repeated in Appendix B.

Table 3. GPIO expansion header (J5) pin mapping.

Pin | Signal | Pin | Signal
1 | +3V3 | 11 | PB12
2 | GND | 12 | PB13
3 | PA0 | 13 | PB14

Pin | Signal | Pin | Signal
4 | PA1 | 14 | PB15
5 | PA8 | 15 | PC0
6 | PA9 | 16 | PC1
7 | PA10 | 17 | PC2
8 | PB2 | 18 | PC3
9 | PB10 | 19 | PC4
10 | PC6 | 20 | PC5

### 4.11 User Interface

User interaction is provided by SW2, a push-button on PB1 (pin 27) with a 10 kΩ pull-up to +3V3, and D1, a user-controllable LED on PB0 (pin 26) driven through a 330 Ω series resistor (R3). Status indication is provided separately by D2 (power, described in Section 4.2) and D4 (USB status, described below), keeping power, USB, and user-programmable indication visually distinct on the silkscreen and in use.

### 4.12 Clock Circuit

An external 8 MHz crystal, Y1 (footprint Crystal_SMD_3225-4Pin_3.2x2.5mm), is connected between PH0-OSC_IN (pin 5) and PH1-OSC_OUT (pin 6), with 18 pF load capacitors C2 and C3 returning each oscillator pin to GND. The crystal and its load capacitors were placed as close as practicable to the MCU oscillator pins, which minimizes stray trace capacitance and loop area around the oscillator network — a standard precaution for reliable crystal startup and frequency accuracy.

### 4.13 Decoupling

Decoupling is applied across every supply domain on the board rather than as a single bulk capacitor: local 100 nF capacitors (C6–C9) are placed at the MCU's digital VDD pins, a 4.7 µF bulk capacitor (C10) supports the digital rail against larger transient loads, and the analog supply is separately filtered with C11 (100 nF) and C12 (1 µF) to reduce coupling of digital switching noise into the ADC/analog reference domain. VCAP1 is decoupled with C1 (4.7 µF), and the regulator input/output are decoupled locally with C4 and C5 as described in Section 4.2.

This layered approach — small local capacitors for high-frequency transient response placed as close as possible to each supply pin, larger bulk capacitance for lower-frequency energy storage, and a dedicated, isolated analog decoupling path — reflects standard mixed-signal power-integrity practice and helps keep the MCU's internal regulator, digital core, and analog peripherals operating within their supply-noise tolerances.

Table 4. Decoupling and bulk capacitance summary.

Reference | Value | Location / Purpose
C1 | 4.7 µF | VCAP1 to GND
C4 | 1 µF | Regulator input (USB_5V)

Reference | Value | Location / Purpose
C5 | 1 µF | Regulator output (+3V3)
C6–C9 | 100 nF (×4) | Local MCU VDD decoupling
C10 | 4.7 µF | Bulk decoupling, digital rail
C11 | 100 nF | Analog supply (VDDA) decoupling
C12 | 1 µF | Analog supply filtering

### 4.14 Test Points

Five labelled test points are included for laboratory probing: TP1 (+3V3), TP2 (GND), TP3 (SWDIO), TP4 (SWCLK), and TP5 (NRST). These provide convenient, connector-free access to the primary power and debug-critical nets. No physical measurements have been taken at these points as part of this submission; their purpose is to support future bring-up and debugging once hardware is available.

## 5. PCB Design

### 5.1 Board Dimensions

The finished PCB measures 80 mm × 60 mm, well within the 100 mm × 100 mm maximum permitted by the competition. This compact envelope was chosen deliberately, rather than filling the full allowed area, to demonstrate that the complete required and supplementary feature set could be achieved in a genuinely compact form factor suitable for bench use, enclosure integration, or embedding in a larger prototype.

### 5.2 Layer Stack / Two-Layer Constraint

The board uses exactly two copper layers (F.Cu and B.Cu), as required by the competition. Working within two layers removes the option of a dedicated internal ground plane or internal power plane, so return-current paths and power distribution had to be managed directly on the top and bottom copper using ground fill zones and deliberate routing discipline rather than being handled implicitly by an inner plane.

### 5.3 Component Placement

The STM32F401RET6 was placed centrally on the board, consistent with its role as the primary routing hub described in Section 4.1. Functional blocks were arranged around it by proximity to their associated MCU pins and by their external connection requirements:

- The USB-C connector (J6) is positioned at the board edge to allow a cable to be inserted without obstruction, with the USB ESD protection device (U2) placed close to it so that the unprotected trace run from connector to ESD device is minimized.
- The power regulator (U3) is located near the USB/power entry point, with its input and output decoupling capacitors (C4, C5) placed immediately adjacent to its pins.
- The crystal (Y1) and its load capacitors (C2, C3) are placed close to the MCU oscillator pins (PH0/PH1) to keep the oscillator loop short.
- The SWD header (J1) is kept accessible at a board edge for probe or cable connection.
- UART, I²C, and SPI headers (J2, J3, J4) are grouped together to simplify wiring during bench use.
- The GPIO expansion header (J5) is positioned for unobstructed access along its own edge.
- The reset button, user button, and all four indicator LEDs are placed for physical accessibility and clear visibility respectively.
- Test points (TP1–TP5) are distributed near their associated nets for convenient probing without interfering with other components.
This placement strategy reduces unnecessary trace length between related components, keeps high-priority short connections (decoupling, oscillator, ESD protection) physically short by construction, and groups connectors and controls logically for a developer using the board on a bench.

### 5.4 Routing Strategy

Routing followed the functional grouping established during placement: signals were kept within their functional region wherever possible, power connections were kept short and direct, and the USB differential pair was routed as a matched, closely-spaced pair from the connector through the ESD device and series resistors to the MCU, without claiming formal impedance-controlled routing, since impedance control was not implemented or documented as part of this submission.

Routing a feature set of this breadth — USB, dual power inputs, SWD, UART, SPI, I²C, a ten-line GPIO expansion header, four indicator LEDs, two user controls, and five test points — using only two copper layers required continuous trade-offs between direct routing and layer changes. Ground-fill zones were used on both layers to recover return-path continuity that a two-layer board cannot obtain from an internal plane, and via placement for layer changes was kept close to the pins being connected to minimize additional trace length introduced by each transition.

### 5.5 Ground Planes

Copper-fill ground zones were poured on both the top and bottom layers, stitched together where practical, rather than relying solely on discrete ground traces. On a two-layer board, these zones serve a genuinely practical role: they provide return-current paths for signals without requiring an explicit routed ground trace alongside every signal, they reduce the amount of dedicated ground routing needed elsewhere, and they generally improve the organization and manufacturability of the copper. These fills are described here as a practical layout aid consistent with standard two-layer design practice; no claim of guaranteed EMI compliance or formal electromagnetic-compatibility qualification is made for this design.

### 5.6 Power Distribution

The 3.3 V rail is distributed from the regulator output outward to the MCU's four VDD pins and the VDDA/VBAT pins, with local decoupling at each destination as described in Section 4.13. Keeping the regulator physically close to the MCU, and keeping each decoupling capacitor physically close to its associated pin, was prioritized over routing convenience wherever the two conflicted, consistent with standard power-integrity practice for MCU-class digital devices.

### 5.7 USB Layout Considerations

The USB-C connector, ESD protection device, and series resistors were placed and routed as a contiguous group at the board edge, with the differential D+/D− pair kept short and routed together from the connector, through U2, through R10/R11, and into PA12/PA11. As noted in Section 5.4, this reflects careful physical grouping and short, matched-length routing rather than a formally impedance-controlled transmission-line design, which was not implemented or documented for this board.

## 6. Major Components

Table 5 summarizes the principal active and passive components used in the design, beyond the general-purpose resistors and capacitors already itemized in Sections 4.2 and 4.13.

Table 5. Major components and their roles.

Reference | Component | Package / Footprint | Role
U1 | STM32F401RET6 | LQFP-64, 10×10 mm, 0.5 mm pitch | Main microcontroller
U2 | USBLC6-2SC6 | SOT-23-6 | USB D+/D− ESD protection
U3 | AP2112K-3.3 | SOT-23-5 | 3.3 V LDO regulator
Y1 | 8 MHz crystal | SMD 3225-4Pin, 3.2×2.5 mm | System clock reference
J6 | USB-C receptacle | GCT USB4105-xx-A, 16-pin | Power input + USB 2.0 data
D3 | SS14 Schottky diode | SMA/SMB (discrete) | External 5 V input protection
J1 | 5-pin header | 2.54 mm pitch | SWD debug interface
J2 / J3 / J4 | 4- / 4- / 6-pin headers | 2.54 mm pitch | UART / I²C / SPI breakout
J5 | 2×10 header | 2.54 mm pitch | GPIO expansion
J7 | 2-pin header | 2.54 mm pitch | External 5 V input
J8 | 2-pin header | 2.54 mm pitch | BOOT0 selection
D1 / D2 / D4 | LEDs | SMD | User / power / USB status indication
SW1 / SW2 | Tactile push-buttons | SMD | Reset / user button

## 7. Major Design Decisions

Building a complete platform, not a minimal breakout

I chose to implement the full set of practical interfaces a developer would expect from an evaluation board — independently accessible UART, SPI, and I²C, a general-purpose GPIO expansion header, and both status and user-programmable indicators — rather than the minimum required to satisfy the competition checklist. This decision shaped nearly every subsequent layout and component choice, since it committed the design to fitting a broader feature set into the same two-layer, 100 mm × 100 mm envelope.

Dual power input with shared regulation

Supporting both USB-C and an external 5 V input through a single shared regulator and decoupling path (Section
4.2) was chosen over implementing two independent regulation paths, in order to keep the power distribution and indication circuitry unified and to avoid duplicating decoupling and test-point infrastructure for two rails that ultimately serve the same purpose.

Dedicated ESD protection ahead of the MCU

Rather than connecting the USB-C data lines directly to the MCU through only series resistors, I added the USBLC6-2SC6 ESD-protection device specifically to intercept transient events at the connector boundary, reflecting the exposed nature of a user-facing USB-C port on a development board that will be repeatedly connected and disconnected.

External SWD rather than an onboard programmer

Integrating an onboard ST-Link-class programmer was considered and deliberately not pursued, in favor of a dedicated external SWD header. This kept the component count, board area, and schematic complexity focused on the evaluation platform itself, while still providing complete programming and debugging capability through widely available external probes.

Independent peripheral headers over a single combined connector

UART, SPI, and I²C were each broken out to their own dedicated header rather than combined onto a single generic connector, so that each interface could be connected to external hardware unambiguously and without adapter cabling, at the cost of additional header footprint on the board.

## 8. Design Considerations

Beyond the major decisions above, the following practical considerations informed component and feature selection throughout the design:

- Practical usefulness — each added feature (external 5 V input, USB status LED, BOOT0 header, test points) was evaluated for genuine development-time value rather than being included simply to lengthen a feature list.
- Board area — every header and component had to justify its footprint within the self-imposed 80 mm × 60 mm outline, which is well under the 100 mm × 100 mm ceiling.
- Component count — passive count was kept proportionate to function; for example, decoupling was placed per supply domain rather than as a single oversized bulk capacitor, but no redundant capacitors were added beyond what each domain required.
- Cost — commodity, widely available parts (SOT-23-class regulators and protection devices, standard 0.1 inch headers) were favored over specialized components where function was equivalent.
- Routing complexity — features that would have required significant additional routing area or layer changes without proportional functional benefit were avoided, consistent with the two-layer constraint discussed in Section 5.2.
- Development value — interfaces likely to be used repeatedly during firmware development (UART, SWD, GPIO expansion) were prioritized for dedicated, unambiguous header access.
- Reliability and protection — the external-input protection diode and the USB ESD device were included specifically to improve the board's tolerance of real bench-use conditions such as hot-plugging and miswired external supplies.
The design deliberately avoided adding features purely to increase apparent complexity; every block described in Section 4 maps to a specific competition requirement or a clearly stated practical benefit.

## 9. Challenges and Solutions

A. Two-layer limitation

Challenge: Many interfaces and support circuits had to be accommodated within only two copper layers, without the routing flexibility an internal plane would provide.
Solution: Functional partitioning of the schematic, central MCU placement, perimeter-oriented header placement, disciplined use of ground-fill zones, and iterative routing passes to resolve congestion.
Outcome: A completed two-layer PCB layout satisfying every required interface within the target footprint.
B. Feature density

Challenge: USB, dual-source power, SWD, UART, SPI, I²C, GPIO expansion, four indicators, two user controls, and five test points all needed to coexist on an 80 mm × 60 mm board.
Solution: Consistent functional grouping during placement (Section 5.3) and deliberate, unambiguous connector choice for each interface.
Outcome: All required and supplementary features fit within the target footprint without compromising accessibility.
C. USB integration

Challenge: The USB-C connector had to simultaneously provide 5 V power delivery and USB 2.0 data connectivity while incorporating ESD protection ahead of the MCU.
Solution: Adoption of the USBLC6-2SC6 protection device, correctly configured CC-termination resistors, 22 Ω data-line series resistors, and structured, unambiguous net naming (USB_DP_RAW / USB_DP_SER / USB_DP, and the corresponding D− nets) to keep the signal path traceable through the schematic.
Outcome: A protected, correctly referenced USB 2.0 data and power path from connector to MCU.
D. Multiple power inputs

Challenge: USB-C and the external 5 V input both needed to feed the same regulated power system without one source interfering with or being back-driven by the other.
Solution: Routing the external 5 V input through D3 (SS14) before it joins the shared USB_5V net, isolating the external path while allowing either source to supply the regulator.
Outcome: A single, unified 5 V bus feeding one regulation and decoupling path regardless of source.
E. MCU power integrity

Challenge: The STM32F401RET6 presents multiple VDD/VSS pin pairs, a VCAP1 pin, and a separate analog supply domain, each with its own decoupling requirement.
Solution: Local 100 nF capacitors at each digital VDD pin, a 4.7 µF bulk capacitor for the digital rail, dedicated analog-domain capacitors (C11, C12), and a VCAP1 capacitor (C1) sized and placed per ST's device guidance.
Outcome: A fully decoupled power delivery network across all MCU supply domains, as documented in Section 4.13.
F. Originality requirement

Challenge: The NUCLEO-F401RE could be consulted as a functional reference, but direct reproduction of its PCB layout was explicitly prohibited by the competition.
Solution: Independent development of the schematic organization, component placement, board outline dimensions, and routing, using the NUCLEO-F401RE only to confirm functional expectations such as pin usage and typical supporting circuitry.

Outcome: An independently laid-out board, discussed further in Section 19 (Originality).

G. Final verification

Challenge: The completed schematic and PCB needed to be confirmed compliant with KiCad's rule-checking tools before the design could be considered finished.
Solution: Iterative ERC and DRC checking, with each reported issue reviewed and either corrected in the design or, where appropriate, formally excluded after engineering review.
Outcome: A clean final verification result, detailed in Section 10.

## 10. Verification and Validation

### 10.1 Electrical Rules Check (ERC)

The completed schematic was checked using KiCad's built-in Electrical Rules Check. The final run returned zero violations and zero warnings, confirming that pin-type conflicts, unconnected required pins, and other schematic-level electrical rule issues had been resolved prior to submission.

Table 6. Final ERC result.

Metric | Result
Violations | 0
Errors | 0
Warnings | 0

### 10.2 Design Rules Check (DRC)

The completed PCB layout was checked using KiCad's Design Rules Check. The final run reported zero DRC violations. Four items were intentionally excluded after engineering review; these correspond to mechanical hole-clearance checks associated with the selected USB-C connector footprint (GCT USB4105-xx-A), which is a known and reviewed characteristic of that footprint rather than an unresolved layout defect.

Table 7. Final DRC result.

Metric | Result
Reported violations | 0
Errors | 0
Intentional exclusions | 4 (reviewed USB-C connector mechanical hole-clearance checks)

Verification Statement
0 reported DRC violations, with 4 reviewed intentional exclusions. These exclusions were examined individually and confirmed to relate to the mechanical hole-clearance geometry of the selected USB-C connector footprint, not to an unresolved electrical or manufacturability issue.

### 10.3 Design-Level Verification

Beyond the automated ERC/DRC checks, the design was reviewed at the schematic level for correct net connectivity against the MCU pin mapping documented in Appendix A, correct polarity and orientation of the ESD-protection and regulator devices, and correct pull-up/pull-down placement on the reset, BOOT0, and I²C nets. This review was performed within KiCad and does not constitute physical electrical measurement; no oscilloscope, multimeter, or other bench instrument was used, since no physical board exists at this stage of the submission.

### 10.4 Fabrication Outputs

Gerber and NC drill files were generated from the finished PCB layout for competition submission. The exported set includes the standard manufacturing layers: F.Cu, B.Cu, F.Mask, B.Mask, F.Silkscreen, B.Silkscreen, F.Paste, B.Paste, Edge.Cuts, the associated drill files, and a Gerber job file where applicable.

Fabrication Status
Gerber and drill files were generated for fabrication/submission. No physical fabrication, assembly, or hardware bring-up has been performed or is claimed for VantageF401RE as part of this report; fabrication was not required by the competition.

## 11. Distinguishing Design Features

The following characteristics, summarized in Table 8, are presented as notable engineering features of the VantageF401RE design that can be independently verified from the submitted schematic and PCB layout. These features provide a strong and technically complete feature set for an STM32 development platform and represent areas in which the design demonstrates additional engineering consideration; they are not presented as a claim of superiority over any other team's submission.

# | Notable Design Characteristic

1 | Complete STM32 development platform rather than a minimal breakout
2 | USB-C connector providing both 5 V power and USB 2.0 connectivity
3 | Dedicated USB ESD protection (USBLC6-2SC6) ahead of the MCU
4 | 22 Ω series resistors on both USB data lines
5 | External 5 V input option in addition to USB-C power
6 | SS14 Schottky protection on the external 5 V input path
7 | Dedicated 5-pin SWD header for external programmer/debugger use
8 | BOOT0 selection header for convenient bootloader entry
9 | Dedicated reset button and independent user button
10 | UART, SPI and I²C each exposed on independent, dedicated headers
11 | 2×10 GPIO expansion header for sensors, displays and prototyping
12 | Five dedicated test points on power and debug-critical nets
13 | Separate power-indication and USB-status LEDs
14 | External 8 MHz crystal placed close to the MCU oscillator pins
15 | Structured decoupling across digital, analog, and VCAP supply domains
16 | Ground-fill copper zones on both layers
17 | Compact 80 mm × 60 mm form factor, well inside the 100 mm × 100 mm limit
18 | Full required feature set achieved within a two-layer stack-up
19 | Completed schematic and PCB verified via ERC/DRC prior to submission
20 | Gerber and drill files generated and packaged for submission

## 12. Final Outcome

The VantageF401RE design was carried through to a complete, verified state satisfying every mandatory competition requirement listed in Table 1, while adding the supplementary features described in Section 11. The finished layout occupies 80 mm × 60 mm on a two-layer PCB, passed KiCad's ERC with zero violations, passed KiCad's DRC with zero reported violations and four reviewed intentional exclusions, and produced a complete Gerber and drill package for submission.

Table 9. Final design specification summary.

Parameter | Specification
Project | VantageF401RE
MCU | STM32F401RET6, LQFP-64
PCB | 2-layer
Board dimensions | 80 mm × 60 mm
Power input | USB-C 5 V / External 5 V (J7)
Regulator | AP2112K-3.3
Core rail | 3.3 V
USB | USB-C connector, USB 2.0
USB protection | USBLC6-2SC6
Debug interface | SWD (external probe)
Clock | 8 MHz external crystal
Serial interfaces | UART, SPI, I²C (dedicated headers)
Expansion | 2×10 GPIO header
User controls | Reset button, user button, BOOT0 selection header
Indicators | User LED, Power LED, USB status LED
Test points | +3V3, GND, SWDIO, SWCLK, NRST
ERC | 0 violations
DRC | 0 reported violations, 4 reviewed intentional exclusions
Fabrication status | Completed design — Gerber/drill files generated — no fabrication claimed

## 13. Limitations and Future Work

VantageF401RE is submitted as a completed design verified at the schematic and PCB-layout level. As fabrication was not required by the competition and was not performed, the following boundaries apply to the current submission. These are stated as the natural boundary between design-level verification and physical prototype validation, not as shortcomings of the design work performed:

- No physical fabrication was performed, as fabrication was not required by the competition.
- Physical electrical measurements (voltage, current, ripple, timing) have not been performed, since no assembled board exists.
- USB hardware enumeration has not been physically verified on a host system.
- Regulator thermal performance under load has not been physically measured.
- Signal integrity, including the USB differential pair, has been verified at the design and layout level only, not experimentally with a network analyzer or TDR.
Future work, should the design proceed beyond the competition, would naturally include fabrication and assembly, hardware bring-up and power-on testing, firmware development and validation, USB enumeration testing against a host operating system, oscilloscope-based signal and power-rail measurements, thermal measurement of the regulator under representative load, and further PCB optimization informed by findings from physical testing.

## 14. Conclusion

VantageF401RE demonstrates that the mandatory requirements of the Mixed Traces PCB Design Competition can be met, and substantially extended, within a genuinely compact two-layer board. Starting from a fixed STM32F401RE microcontroller and a strict set of constraints on size, layer count, and layout originality, I built a complete evaluation and development platform incorporating dual-source power, protected USB-C connectivity, external debug access, independent UART/SPI/I²C breakout, GPIO expansion, user controls and indicators, and structured decoupling, and carried it through to a design verified clean by KiCad's ERC and DRC tools.

The NUCLEO-F401RE was consulted only as a functional reference; the schematic organization, component placement, board dimensions, and routing presented in this report I independently developed. With Gerber and drill files generated and packaged for submission, VantageF401RE is presented as a compact, feature-rich, independently designed STM32F401RE development platform with documented design-level verification, intended to remain useful as a development tool beyond the scope of the competition itself.

## Appendix A — MCU Pin Mapping

This appendix consolidates the complete STM32F401RET6 pin usage referenced throughout the report.

Table 10. Power and ground pin mapping.

Signal | Pin(s) | Net
VDD | 19, 32, 48, 64 | +3V3
VSS | 18, 31, 47, 63 | GND
VDDA / VREF+ | 13 | +3V3
VSSA / VREF− | 12 | GND
VBAT | 1 | +3V3
VCAP1 | 30 | 4.7 µF to GND (C1)

Table 11. Clock, reset, and BOOT pin mapping.

Signal | Pin | Net / Function
PH0-OSC_IN | 5 | 8 MHz crystal (Y1)
PH1-OSC_OUT | 6 | 8 MHz crystal (Y1)
NRST | 7 | Reset network (R1, SW1) / SWD / J1 / TP5
BOOT0 | 60 | R2 pull-down, J8 BOOT_SEL

Table 12. Interface and peripheral pin mapping.

Signal | Pin | Net / Function
PA13 | 46 | SWDIO (J1)
PA14 | 49 | SWCLK (J1)
PB0 | 26 | USER_LED (D1) via R3
PB1 | 27 | User button (SW2), 10 kΩ pull-up
PA2 | 16 | UART_TX (J2)
PA3 | 17 | UART_RX (J2)
PB6 | 58 | I2C_SCL (J3), R6 pull-up
PB7 | 59 | I2C_SDA (J3), R7 pull-up
PA5 | 21 | SPI_SCK (J4)
PA6 | 22 | SPI_MISO (J4)
PA7 | 23 | SPI_MOSI (J4)
PA4 | 20 | SPI_CS (J4)

Signal | Pin | Net / Function
PA11 | 44 | USB_DM
PA12 | 45 | USB_DP
PB5 | 57 | USB_STATUS (D4) via R12

Note
PB11 is not available as a GPIO on the STM32F401RET6; this physical location is occupied by VCAP1 (pin
30) and is not present in the GPIO expansion mapping in Appendix B.

## Appendix B — Interface Header Mapping

Table 13. J1 — SWD header (5-pin).

Pin | Signal
1 | +3V3
2 | SWDIO
3 | GND
4 | SWCLK
5 | NRST

Table 14. J2 — UART header (4-pin).

Pin | Signal
1 | +3V3
2 | GND
3 | UART_TX
4 | UART_RX

Table 15. J3 — I²C header (4-pin).

Pin | Signal
1 | +3V3
2 | GND
3 | I2C_SCL
4 | I2C_SDA

Table 16. J4 — SPI header (6-pin).

Pin | Signal
1 | +3V3
2 | GND
3 | SPI_SCK
4 | SPI_MISO
5 | SPI_MOSI
6 | SPI_CS

Table 17. J5 — GPIO expansion header (2×10).

Pin | Signal | Pin | Signal
1 | +3V3 | 11 | PB12
2 | GND | 12 | PB13
3 | PA0 | 13 | PB14
4 | PA1 | 14 | PB15
5 | PA8 | 15 | PC0
6 | PA9 | 16 | PC1
7 | PA10 | 17 | PC2
8 | PB2 | 18 | PC3
9 | PB10 | 19 | PC4
10 | PC6 | 20 | PC5

Table 18. J7 — External 5 V input (2-pin) and J8 — BOOT_SEL (2-pin).

Header | Pin | Signal
J7 | 1 | 5V_EXT → D3 (SS14) → USB_5V
J7 | 2 | GND
J8 | 1 | BOOT0
J8 | 2 | +3V3

## Appendix C — Repository Structure

The supporting design files for VantageF401RE are organized in the project's GitHub repository as summarized below, separating the editable KiCad source, generated verification reports, fabrication outputs, documentation, and the bill of materials into clearly labelled directories.

VantageF401RE/
├── bom/
│ ├── Final Component Selection.xlsx
│
├── docs/
│ ├── Major Decisions.md
│ └── Vantage Initial Block Diagram.png ├── kicad/
│ ├── README.md
│ ├── VantageF401RE.kicad_pro
│ ├── VantageF401RE.kicad_sch │ └── VantageF401RE.kicad_pcb
├── results/
│ ├── README.md
│ ├── VantageF401RE_ERC_Report.html │ └── VantageF401RE_DRC_Report.html ├── gerbers/
│ └── VantageF401RE_Gerbers.zip
├── pdf/
│ └── VantageF401RE_Final_Design_Report.pdf └── README.md

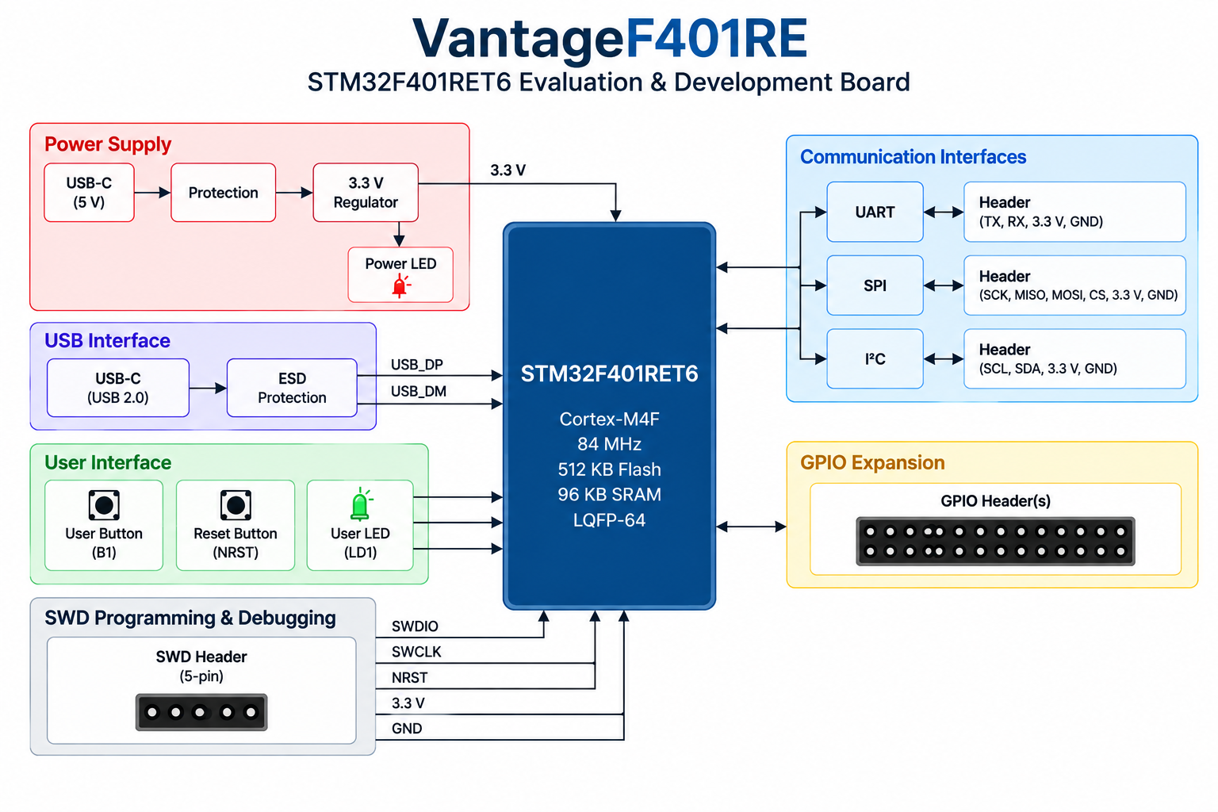
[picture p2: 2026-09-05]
docs/VantageF401RE_Initial_Block_Diagram.png

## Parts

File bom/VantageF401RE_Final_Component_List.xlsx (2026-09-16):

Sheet: Final BOM
VantageF401RE — Final Component List / BOM
Authoritative source: supplied final KiCad schematic screenshots
PCB: 2-layer, 80 mm × 60 mm | MCU: STM32F401RET6 | Total populated references: 47
Reference | Category | Value / Part | Footprint | Qty | Function | Notes
U1 | MCU | STM32F401RET6 | Package_QFP:LQFP-64_10x10mm_P0.5mm | 1 | Main microcontroller | STM32F401RETx symbol; 64-pin LQFP
U2 | USB Protection | USBLC6-2SC6 | Package_TO_SOT_SMD:SOT-23-6 | 1 | USB ESD protection | USB 2.0 D+/D- protection
U3 | Voltage Regulator | AP2112K-3.3 | Package_TO_SOT_SMD:SOT-23-5 | 1 | 3.3 V LDO regulator | USB_5V to +3V3
J1 | Connector | SWD | Connector_PinHeader_2.54mm:PinHeader_1x05_P2.54mm_Vertical | 1 | SWD programming/debug | VCC, SWDIO, GND, SWCLK, NRST
J2 | Connector | UART | Connector_PinHeader_2.54mm:PinHeader_1x04_P2.54mm_Vertical | 1 | UART expansion | +3V3, GND, TX, RX
J3 | Connector | I2C | Connector_PinHeader_2.54mm:PinHeader_1x04_P2.54mm_Vertical | 1 | I²C expansion | +3V3, GND, SCL, SDA
J4 | Connector | SPI | Connector_PinHeader_2.54mm:PinHeader_1x06_P2.54mm_Vertical | 1 | SPI expansion | +3V3, GND, SCK, MISO, MOSI, CS
J5 | Connector | GPIO | Connector_PinHeader_2.54mm:PinHeader_2x10_P2.54mm_Vertical | 1 | GPIO expansion | 20-pin header
J6 | Connector | USB-C | Connector_USB:USB_C_Receptacle_GCT_USB4105-xx-A_16P_TopMnt_Horizontal | 1 | USB power/data | USB 2.0 Type-C receptacle
J7 | Connector | EXT_5V | Connector_PinHeader_2.54mm:PinHeader_1x02_P2.54mm_Vertical | 1 | External 5 V input | Protected by SS14
J8 | Connector | BOOT_SEL | Connector_PinHeader_2.54mm:PinHeader_1x02_P2.54mm_Vertical | 1 | Boot-mode selection | BOOT0 to +3V3 jumper
Y1 | Crystal | 8MHz | Crystal:Crystal_SMD_3225-4Pin_3.2x2.5mm | 1 | High-speed external oscillator | HSE crystal
R1 | Resistor | 10kΩ | Resistor_SMD:R_0805_2012Metric | 1 | NRST pull-up | +3V3 to NRST
R2 | Resistor | 10kΩ | Resistor_SMD:R_0805_2012Metric | 1 | BOOT0 pull-down | BOOT0 to GND
R3 | Resistor | 330Ω | Resistor_SMD:R_0805_2012Metric | 1 | User LED current limiting | PB0 to D1
R4 | Resistor | 10kΩ | Resistor_SMD:R_0805_2012Metric | 1 | User button pull-up | PB1 to +3V3
R5 | Resistor | 4.7kΩ | Resistor_SMD:R_0805_2012Metric | 1 | I²C SCL pull-up | +3V3 to I2C_SCL
R6 | Resistor | 4.7kΩ | Resistor_SMD:R_0805_2012Metric | 1 | I²C SDA pull-up | +3V3 to I2C_SDA
R7 | Resistor | 5.1kΩ | Resistor_SMD:R_0805_2012Metric | 1 | USB-C CC1 pull-down | CC1 to GND
R8 | Resistor | 5.1kΩ | Resistor_SMD:R_0805_2012Metric | 1 | USB-C CC2 pull-down | CC2 to GND
R9 | Resistor | 1kΩ | Resistor_SMD:R_0805_2012Metric | 1 | Power LED current limiting | +3V3 to D2
R10 | Resistor | 22Ω | Resistor_SMD:R_0805_2012Metric | 1 | USB D+ series resistor | USB_DP_SER to USB_DP
R11 | Resistor | 22Ω | Resistor_SMD:R_0805_2012Metric | 1 | USB D− series resistor | USB_DM_SER to USB_DM
R12 | Resistor | 1kΩ | Resistor_SMD:R_0805_2012Metric | 1 | USB status LED current limiting | PB5 to D4
C1 | Capacitor | 4.7µF | Capacitor_SMD:C_0805_2012Metric | 1 | VCAP1 capacitor | VCAP1 to GND
C2 | Capacitor | 18pF | Capacitor_SMD:C_0805_2012Metric | 1 | HSE load capacitor | PH0 side to GND
C3 | Capacitor | 18pF | Capacitor_SMD:C_0805_2012Metric | 1 | HSE load capacitor | PH1 side to GND
C4 | Capacitor | 1µF | Capacitor_SMD:C_0805_2012Metric | 1 | LDO input decoupling | USB_5V to GND
C5 | Capacitor | 1µF | Capacitor_SMD:C_0805_2012Metric | 1 | LDO output decoupling | +3V3 to GND
C6 | Capacitor | 100nF | Capacitor_SMD:C_0805_2012Metric | 1 | MCU VDD decoupling | +3V3 to GND
C7 | Capacitor | 100nF | Capacitor_SMD:C_0805_2012Metric | 1 | MCU VDD decoupling | +3V3 to GND
C8 | Capacitor | 100nF | Capacitor_SMD:C_0805_2012Metric | 1 | MCU VDD decoupling | +3V3 to GND
C9 | Capacitor | 100nF | Capacitor_SMD:C_0805_2012Metric | 1 | MCU VDD decoupling | +3V3 to GND
C10 | Capacitor | 4.7µF | Capacitor_SMD:C_0805_2012Metric | 1 | Bulk 3.3 V decoupling | +3V3 to GND
C11 | Capacitor | 100nF | Capacitor_SMD:C_0805_2012Metric | 1 | Analog supply decoupling | VDDA/VREF+ supply
C12 | Capacitor | 1µF | Capacitor_SMD:C_0805_2012Metric | 1 | Analog supply decoupling | VDDA/VREF+ supply
D1 | LED | USER_LED | LED_SMD:LED_0805_2012Metric | 1 | User indicator | Driven by PB0
D2 | LED | POWER | LED_SMD:LED_0805_2012Metric | 1 | 3.3 V power indicator | On when +3V3 is present
D3 | Diode | SS14 | Diode_SMD:D_SMA | 1 | External 5 V reverse-polarity protection | EXT_5V to USB_5V
D4 | LED | USB_STATUS | LED_SMD:LED_0805_2012Metric | 1 | USB/status indicator | Driven by PB5
SW1 | Switch | SW_Push | Button_Switch_THT:SW_PUSH_6mm | 1 | Reset button | NRST to GND
SW2 | Switch | USER_BTN | Button_Switch_THT:SW_PUSH_6mm | 1 | User button | PB1 to GND
TP1 | Test Point | TP_3V3 | TestPoint:TestPoint_Plated_Hole_D2.0mm | 1 | 3.3 V test point | +3V3
TP2 | Test Point | TP_GND | TestPoint:TestPoint_Plated_Hole_D2.0mm | 1 | Ground test point | GND
TP3 | Test Point | TP_SWDIO | TestPoint:TestPoint_Plated_Hole_D2.0mm | 1 | SWDIO test point | SWDIO
TP4 | Test Point | TP_SWCLK | TestPoint:TestPoint_Plated_Hole_D2.0mm | 1 | SWCLK test point | SWCLK
TP5 | Test Point | TP_NRST | TestPoint:TestPoint_Plated_Hole_D2.0mm | 1 | Reset test point | NRST

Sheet: Category Summary
Category | Quantity
MCU | 1
USB Protection | 1
Voltage Regulator | 1
Connector | 8
Crystal | 1
Resistor | 12
Capacitor | 12
LED | 3
Diode | 1
Switch | 2
Test Point | 5
Total references | 47

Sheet: Interface Mapping
Interface / Function | Connector / Reference | MCU Pins / Nets | Notes
SWD | J1 | PA13 = SWDIO; PA14 = SWCLK; NRST | 5-pin debug/programming header
UART | J2 | PA2 = UART_TX; PA3 = UART_RX | 3.3 V logic
I²C | J3 | PB6 = I2C_SCL; PB7 = I2C_SDA | R5/R6 = 4.7 kΩ pull-ups
SPI | J4 | PA5 = SCK; PA6 = MISO; PA7 = MOSI; PA4 = CS | 3.3 V logic
GPIO | J5 | PA0, PA1, PA8, PA9, PA10, PB2, PB10, PC6, PB12–PB15, PC0–PC5 | 20-pin expansion header
USB 2.0 | J6/U2/R10/R11 | PA11 = USB_DM; PA12 = USB_DP | USB-C, ESD protection and 22 Ω series resistors
Reset | SW1/R1 | NRST | 10 kΩ pull-up; pushbutton to GND
Boot select | J8/R2 | BOOT0 | 10 kΩ pull-down; jumper to +3V3
User LED | D1/R3 | PB0 | 330 Ω current limiting
User button | SW2/R4 | PB1 | 10 kΩ pull-up
USB status LED | D4/R12 | PB5 | 1 kΩ current limiting
Power LED | D2/R9 | +3V3 | 1 kΩ current limiting
External power | J7/D3 | EXT_5V → SS14 → USB_5V | Reverse-polarity protection

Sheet: Notes & BOM Guidance
Item | Details
Numbering correction | R1 reset pull-up, R2 BOOT0 pull-down, R3 user LED, R4 user-button pull-up, R5/R6 I²C pull-ups, R7/R8 USB-C CC resistors, R9 power LED, R10/R11 USB series resistors, R12 USB status LED.
Source of truth | Use the final KiCad schematic as the source of truth if any text in older documentation differs from this workbook.
BOM sourcing | Manufacturer/MPN and estimated prices are intentionally not fabricated here. They should be filled from the actual selected supplier/part before procurement.
Total | 47 populated references are represented: U1–U3, J1–J8, Y1, R1–R12, C1–C12, D1–D4, SW1–SW2, TP1–TP5.

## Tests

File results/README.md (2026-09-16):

# VantageF401RE — Final Verification Results

## Overview

The **VantageF401RE** is a custom STM32F401RE-based 2-layer evaluation and development board designed as part of the **Mixed Traces PCB Design Competition** conducted by **Mixed Signals, Electronics Association of MEC**.

The design was developed from the ground up in **KiCad**, with emphasis on electrical correctness, signal accessibility, power integrity, protection, usability, compact PCB organization, and practical embedded-system development.

This folder contains the final **Electrical Rules Check (ERC)** and **Design Rules Check (DRC)** results for the completed design.

---

## Final Verification Status

The completed schematic and PCB layout were subjected to KiCad's electrical and physical design-rule verification.

### Electrical Rules Check — ERC

The final schematic achieved:

- **ERC Violations: 0**
- **Errors: 0**
- **Warnings: 0**

This confirms that the completed schematic passed the electrical rules check without reported violations.

### Design Rules Check — DRC

The final PCB achieved:

- **DRC Errors: 0**
- **Known DRC Violations: 0**
- **Intentional Exclusions: 4**

The four exclusions correspond to reviewed USB-C connector mechanical hole-clearance checks associated with the selected connector footprint.

The exclusions were intentional and reviewed during the final PCB verification process.

---

## What We Achieved

The VantageF401RE design was developed as a complete, functional STM32 development-board platform rather than a minimal MCU breakout.

### Core Processing

- **STM32F401RET6** ARM Cortex-M4 microcontroller
- 512 KB Flash
- 96 KB SRAM
- Up to 84 MHz operating frequency
- External 8 MHz crystal oscillator
- Dedicated VCAP and power decoupling

### Power System

- USB-C 5 V power input
- External 5 V input
- Schottky-diode protected external supply path
- AP2112K 3.3 V low-dropout regulator
- Separate input and output bulk decoupling
- Dedicated MCU power decoupling
- Analog supply decoupling
- Power indication LED
- Accessible 3.3 V and GND test points

### Programming and Debugging

- Dedicated **SWD interface**
- SWDIO
- SWCLK
- NRST
- VCC
- GND
- Dedicated reset push button
- BOOT0 configuration header
- BOOT0 pull-down

### Communication Interfaces

The board provides dedicated headers for:

- **UART**
- **SPI**
- **I²C**

This allows the board to interface easily with external sensors, displays, memories, communication modules, and other embedded peripherals.

### USB Interface

The board incorporates a USB-C interface with:

- USB 2.0 D+ and D− connectivity
- CC1 and CC2 configuration resistors
- Dedicated USB ESD protection
- USB differential-pair routing
- Series termination resistors
- USB status indication
- USB 5 V power extraction

### User Interface

- Dedicated user push button
- User LED
- Reset button
- Power LED
- USB status LED
- BOOT selection header

### Expansion

A dedicated **2×10 GPIO header** exposes multiple STM32 GPIOs along with power and ground connections, providing convenient access for external hardware and experimentation.

### Debugging and Measurement

Dedicated test points are provided for:

- 3.3 V
- GND
- SWDIO
- SWCLK
- NRST

These improve accessibility during debugging, probing, and laboratory testing.

---

## Engineering Decisions

The design was developed with emphasis on more than simply satisfying the mandatory competition requirements.

Key design considerations included:

- Central placement of the STM32 MCU for organized routing
- Short and direct USB protection path
- Dedicated USB power and data sections
- Localized power regulation circuitry
- Appropriate MCU decoupling
- Dedicated analog supply filtering
- Crystal oscillator placed close to the MCU
- Dedicated SWD access
- Accessible peripheral headers
- Ground planes for improved return-current paths
- Structured separation of functional PCB regions
- Compact **80 mm × 60 mm** board outline
- Two-layer PCB implementation

---

## Design Validation

The final design was checked at both schematic and PCB levels.

### Schematic Validation

ERC was performed on the completed schematic to identify:

- Electrical connectivity issues
- Unconnected or incorrectly connected pins
- Power-related rule violations
- Driver conflicts
- Other schematic-level rule violations

**Final result: 0 ERC violations.**

### PCB Validation

DRC was performed on the completed PCB to identify:

- Clearance violations
- Track and pad rule violations
- Copper connectivity problems
- Board-edge violations
- Unrouted connections
- Other PCB design-rule violations

**Final result: 0 reported DRC violations**, with 4 reviewed intentional exclusions related to USB-C connector mechanical clearances.

---

## Design Strengths

VantageF401RE combines the core functionality expected from an STM32 development platform with additional practical features that improve its usefulness as a development and experimentation board.

The design integrates:

- USB-C connectivity
- Protected USB data lines
- Regulated 3.3 V power
- External 5 V input
- SWD debugging
- BOOT configuration
- UART
- SPI
- I²C
- GPIO expansion
- User controls
- Multiple indicators
- Test points
- Crystal oscillator
- Dedicated power filtering
- Ground planes

This provides a broader and more practical development environment while remaining within the competition's **2-layer PCB** and **100 mm × 100 mm maximum board-size** constraints.

---

## Final Design Outcome

The project progressed from the initial concept and block-level planning through component selection, schematic development, PCB placement, routing, verification, and fabrication-file generation.

The completed design now includes:

**Concept → Component Selection → Schematic → PCB Layout → Routing → ERC/DRC Verification → Gerber Generation**

The final design files are provided in the repository for inspection and further development.

---

## Repository Contents

### `kicad/`

Contains the complete editable KiCad project:

- Schematic
- PCB layout
- KiCad project file

### `bom/`

Contains the component-selection and BOM documentation.

### `docs/`

Contains project documentation including:

- Major design decisions
- Initial block diagram
- Progress evaluation documentation

### `results/`

Contains the final ERC and DRC verification reports.

### `gerbers/`

Contains the generated Gerber and drill files packaged for PCB fabrication.

### `pdf/`

Reserved for the final project documentation PDF.

---

## Final Statement

**VantageF401RE represents a complete, verified, and fabrication-ready PCB design developed in KiCad around the STM32F401RET6.**

The design focuses on:

**Functionality • Reliability • Accessibility • Protection • Verification • Practical Embedded Development**

The final ERC and DRC results provide documented verification of the completed schematic and PCB design, while the complete KiCad project and fabrication files are provided for transparency and evaluation.

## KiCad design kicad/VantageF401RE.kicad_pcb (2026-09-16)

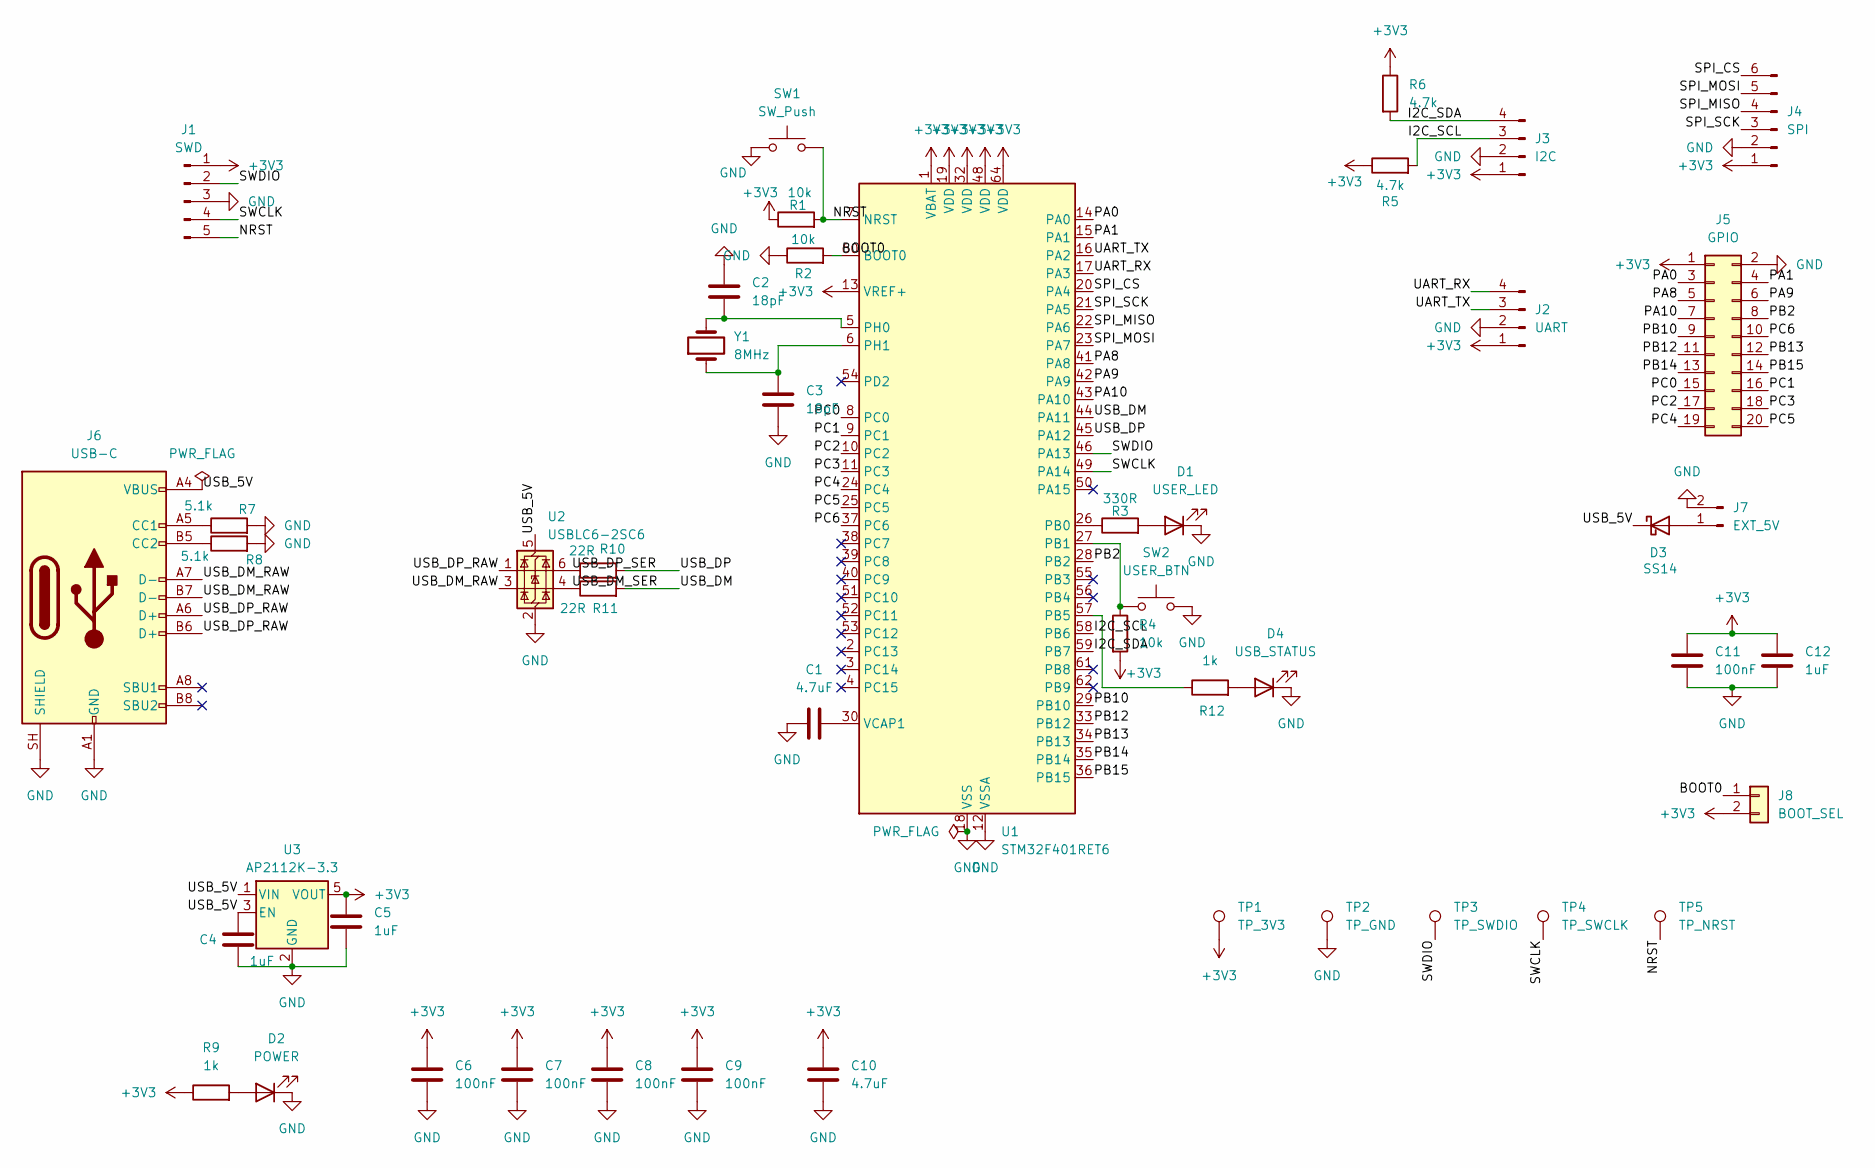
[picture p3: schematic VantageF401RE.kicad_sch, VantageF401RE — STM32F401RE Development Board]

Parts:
C1, C10: 4.7uF; C_0805_2012Metric
C2, C3: 18pF; C_0805_2012Metric
C4, C5, C12: 1uF; C_0805_2012Metric
C6, C7, C8, C9, C11: 100nF; C_0805_2012Metric
D1: USER_LED; LED_0805_2012Metric
D2: POWER; LED_0805_2012Metric
D3: SS14; D_SMA
D4: USB_STATUS; LED_0805_2012Metric
J1: SWD; PinHeader_1x05_P2.54mm_Vertical
J2: UART; PinHeader_1x04_P2.54mm_Vertical
J3: I2C; PinHeader_1x04_P2.54mm_Vertical
J4: SPI; PinHeader_1x06_P2.54mm_Vertical
J5: GPIO; PinHeader_2x10_P2.54mm_Vertical
J6: USB-C; USB_C_Receptacle_GCT_USB4105-xx-A_16P_TopMnt_Horizontal
J7: EXT_5V; PinHeader_1x02_P2.54mm_Vertical
J8: BOOT_SEL; PinHeader_1x02_P2.54mm_Vertical
R1, R2, R4: 10k; R_0805_2012Metric
R3: 330R; R_0805_2012Metric
R5, R6: 4.7k; R_0805_2012Metric
R7, R8: 5.1k; R_0805_2012Metric
R9, R12: 1k; R_0805_2012Metric
R10, R11: 22R; R_0805_2012Metric
SW1: SW_Push; SW_PUSH_6mm
SW2: USER_BTN; SW_PUSH_6mm
TP1: TP_3V3; TestPoint_Plated_Hole_D2.0mm
TP2: TP_GND; TestPoint_Plated_Hole_D2.0mm
TP3: TP_SWDIO; TestPoint_Plated_Hole_D2.0mm
TP4: TP_SWCLK; TestPoint_Plated_Hole_D2.0mm
TP5: TP_NRST; TestPoint_Plated_Hole_D2.0mm
U1: STM32F401RET6; LQFP-64_10x10mm_P0.5mm
U2: USBLC6-2SC6; SOT-23-6
U3: AP2112K-3.3; SOT-23-5
Y1: 8MHz; Crystal_SMD_3225-4Pin_3.2x2.5mm

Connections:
+3V3: C5.1, C6.1, C7.1, C8.1, C9.1, C10.1, C11.1, C12.1, J1.1, J2.1, J3.1, J4.1, J5.1, J8.2, R1.1, R4.2, R5.1, R6.1, R9.1, TP1.1 (1_1), U1.1 (VBAT), U1.13 (VREF+), U1.19 (VDD), U1.32 (VDD), U1.48 (VDD), U1.64 (VDD), U3.5 (VOUT)
/BOOT0: J8.1, R2.2, U1.60 (BOOT0)
/I2C_SCL: J3.3, R5.2, U1.58 (PB6)
/I2C_SDA: J3.4, R6.2, U1.59 (PB7)
/NRST: J1.5, R1.2, SW1.2, TP5.1 (1_1), U1.7 (NRST)
/PA0: J5.3, U1.14 (PA0)
/PA1: J5.4, U1.15 (PA1)
/PA8: J5.5, U1.41 (PA8)
/PA9: J5.6, U1.42 (PA9)
/PA10: J5.7, U1.43 (PA10)
/PB2: J5.8, U1.28 (PB2)
/PB10: J5.9, U1.29 (PB10)
/PB12: J5.11, U1.33 (PB12)
/PB13: J5.12, U1.34 (PB13)
/PB14: J5.13, U1.35 (PB14)
/PB15: J5.14, U1.36 (PB15)
/PC0: J5.15, U1.8 (PC0)
/PC1: J5.16, U1.9 (PC1)
/PC2: J5.17, U1.10 (PC2)
/PC3: J5.18, U1.11 (PC3)
/PC4: J5.19, U1.24 (PC4)
/PC5: J5.20, U1.25 (PC5)
/PC6: J5.10, U1.37 (PC6)
/SPI_CS: J4.6, U1.20 (PA4)
/SPI_MISO: J4.4, U1.22 (PA6)
/SPI_MOSI: J4.5, U1.23 (PA7)
/SPI_SCK: J4.3, U1.21 (PA5)
/SWCLK: J1.4, TP4.1 (1_1), U1.49 (PA14)
/SWDIO: J1.2, TP3.1 (1_1), U1.46 (PA13)
/UART_RX: J2.4, U1.17 (PA3)
/UART_TX: J2.3, U1.16 (PA2)
/USB_5V: C4.1, D3.1 (K), J6.A4 (VBUS), J6.A9 (VBUS), J6.B4 (VBUS), J6.B9 (VBUS), U2.5 (VBUS), U3.1 (VIN), U3.3 (EN)
/USB_DM: R11.2, U1.44 (PA11)
/USB_DM_RAW: J6.A7 (D-), J6.B7 (D-), U2.3 (I/O2)
/USB_DM_SER: R11.1, U2.4 (I/O2)
/USB_DP: R10.2, U1.45 (PA12)
/USB_DP_RAW: J6.A6 (D+), J6.B6 (D+), U2.1 (I/O1)
/USB_DP_SER: R10.1, U2.6 (I/O1)
GND: C1.1, C2.1, C3.2, C4.2, C5.2, C6.2, C7.2, C8.2, C9.2, C10.2, C11.2, C12.2, D1.1 (K), D2.1 (K), D4.1 (K), J1.3, J2.2, J3.2, J4.2, J5.2, J6.A1 (GND), J6.A12 (GND), J6.B1 (GND), J6.B12 (GND), J6.SH (SHIELD), J7.2, R2.1, R7.2, R8.2, SW1.1, SW2.2, TP2.1 (1_1), U1.12 (VSSA), U1.18 (VSS), U1.31 (VSS), U1.47 (VSS), U1.63 (VSS), U2.2 (GND), U3.2 (GND)
unnamed: D1.2 (A), R3.2
unnamed: D2.2 (A), R9.2
unnamed: D3.2 (A), J7.1
unnamed: D4.2 (A), R12.2
unnamed: J6.A5 (CC1), R7.1
unnamed: J6.B5 (CC2), R8.1
unnamed: R3.1, U1.26 (PB0)
unnamed: R4.1, SW2.1, U1.27 (PB1)
unnamed: R12.1, U1.57 (PB5)
unnamed: C2.2, U1.5 (PH0), Y1.2
unnamed: C3.1, U1.6 (PH1), Y1.1
unnamed: C1.2, U1.30 (VCAP1)

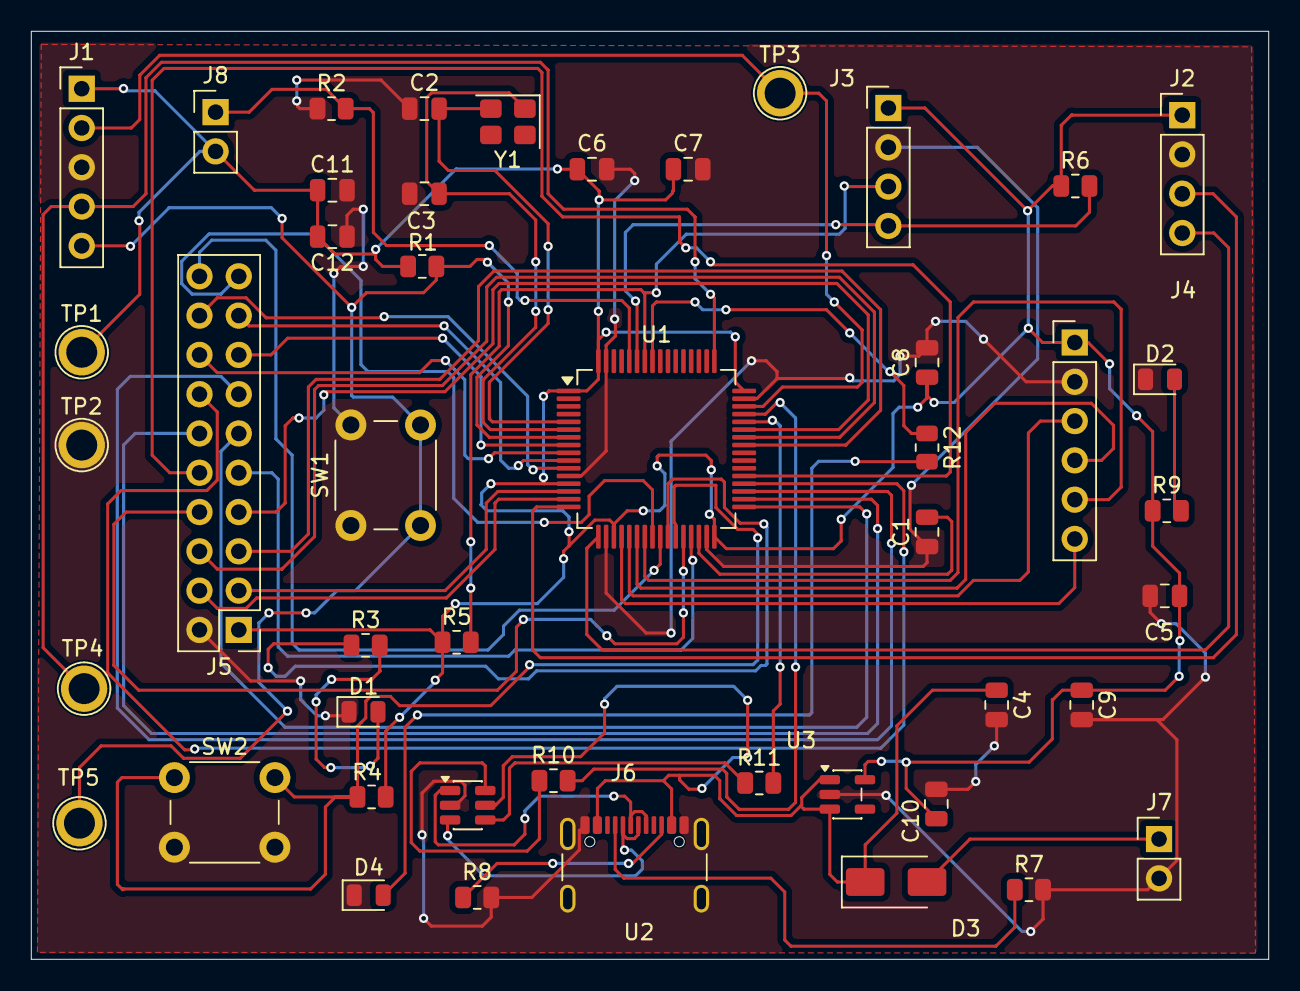
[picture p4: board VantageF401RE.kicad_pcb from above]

Board: 2 copper layers, 80.0 x 60.0 mm, 47 parts (0 on the bottom side), 51 nets.

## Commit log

2026-09-05 Add initial VantageF401RE project documentation
    [VantageF401RE_Initial_Component_Selection.xlsx]
2026-09-05 Enhance README with project details and stages
    Updated the README to provide detailed information about the KiCad design files and the current design stage of the VantageF401RE project.
2026-09-05 Revise major design decisions for STM32 board
    Updated the major design decisions for the STM32 evaluation board, including detailed specifications for MCU, board purpose, size, interfaces, and design objectives.
2026-09-16 Add final KiCad schematic and PCB
    [VantageF401RE.kicad_pcb, VantageF401RE.kicad_sch]
2026-09-16 Revise README for VantageF401RE KiCad project
    Updated README to provide comprehensive details about the VantageF401RE KiCad design files, including project overview, design verification, specifications, and instructions for opening the project.
2026-09-16 Update Major Design Decisions for VantageF401RE board
    Expanded the Major Design Decisions document with detailed sections on board features, design objectives, and verification results for the VantageF401RE STM32 evaluation board.
2026-09-16 Create BOM folder
2026-09-16 Add final component list
    [VantageF401RE_Final_Component_List.xlsx]
2026-09-16 Add final Gerber fabrication files
2026-09-16 Add README for VantageF401RE Gerber fabrication files
    Added README.md for VantageF401RE Gerber files with details on included fabrication files, PCB specifications, and verification.
